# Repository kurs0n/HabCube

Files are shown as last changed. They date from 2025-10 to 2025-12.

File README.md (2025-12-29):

# HabCube

## Description

The "Intelligent Cube" is an IoT device that supports users in forming and maintaining daily habits. Habits are defined in a mobile application, which allows for configuration and the presentation of statistics regarding progress.

## Prototype Video
 
https://youtu.be/eo05IGiR9LY

## Introduction

The goal of this project is to create a complete Internet of Things (IoT) system designed to operate on a local network. The system combines hardware (the physical cube) with a mobile application that allows users to define, configure, and track their habits, as well as view statistics on their progress.

The project integrates knowledge from electronics, computer science, network programming, and embedded systems engineering. The work covers both the hardware layer (the cube's design and implementation) and the software layer (server-side communication, backend, mobile user interface, and overall system integration).

## Project Goals

### General Goals
- To create a fully functional IoT system operating within a local network.
- To achieve high effectiveness in helping users build and sustain positive habits.
- To design a system that increases user motivation and engagement in the process of self-improvement.
- To develop a final product that genuinely improves users' quality of life by supporting them in achieving their habit-related goals.

### Educational Goals
- To understand the practical aspects of building end-to-end IoT systems.
- To learn how to integrate hardware and software into a single cohesive system.
- To develop teamwork and project management skills.
- To gain experience in planning, implementing, testing, and documenting a complex technical project.
- To learn which motivational mechanisms are most effective in habit formation and how to design engaging and intuitive user interactions.

## Project Scope

### Key Features
- **Habit Configuration**: Defining and managing habits through a mobile application.
- **Progress Tracking**: Monitoring user progress and presenting it through statistics.
- **Motivational Feedback**: Providing users with visual, sound, and light-based "dopamine hits" to reinforce positive actions.

### System Architecture
The system consists of three main components:
1.  **The Intelligent Cube**: A physical device based on an ESP32 microcontroller that acts as the primary user interaction point.
2.  **Central Server**: A backend service responsible for handling communication with the cube, processing data, and storing user statistics.
3.  **Mobile Application**: A user interface for configuring the cube, defining habits, and viewing progress data.

All components communicate over a local Wi-Fi network.

---

## Tools and Technologies

### Software / Backend
* **Language:** Python 3.9+
* **Framework:** Flask
* **Database ORM:** SQLAlchemy
* **API Documentation:** Flasgger (Swagger UI)
* **Serialization:** Python Dataclasses (DTOs)
* **Deployment:** Google Cloud Run (Dockerized)

### Mobile App / UI
* **Framework:** React Native (Expo)
* **Language:** TypeScript
* **Navigation:** React Navigation
* **HTTP Client:** Axios
* **State Management:** React Hooks (Custom Hooks)
* **UI Components:** React Native Vector Icons (Ionicons), Safe Area Context

### 3D Design & Manufacturing
* **Software:** Autodesk Fusion 360
* **Files:** `HabCube.f3z` (Source), `.stl` (Production)
* **Method:** FDM 3D Printing (PLA/PETG)
* **Components:**
    * `new_cube.stl`: Main frame with screen mounts.
    * `new_cap.stl`: Protective lid/cover.

### Database
* **Engine:** PostgreSQL 13+
* **Production:** Google Cloud SQL
* **Caching:** Redis (Google Cloud Memorystore)

### Hardware
* **Microcontroller:** ESP32
* **Peripherals:** 4 OLED Screens (I2C, SPI), Gyroscope, Multiplexer, 2 Tact switches, Audio amplifier, Speaker, LEDs.

### DevOps & Management
* **Containerization:** Docker, Docker Compose
* **CI/CD:** GitHub Actions
* **Version Control:** Git, GitHub
* **Project Management:** GitHub Projects (Kanban board)

---

## Development Setup

### Environment Configuration

It is recommended to enable pre-commit hooks (instructions below).

**IMPORTANT:**
First, run the setup script which automatically adds `export CURRENT_UID` to your `~/.bashrc` (this avoids permission issues with files and folders later):

```bash
./setup-env.sh
source ~/.bashrc
```

### First Run
```bash
# 1. Build the image
docker-compose up -d --build

# 2. Check container status (or use GUI)
docker-compose ps

# 3. View logs
docker-compose logs -f backend

# 4. Check app health
curl http://localhost:5000/health
```
### Running the Application
```bash
# You can run it via Docker Compose or using the MAKEFILE
docker-compose up -d

# Stop
docker-compose down
```
### Using Makefile (Recommended)
The Makefile automatically exports CURRENT_UID:
```bash
make init      # First run / Initialization
make up        # Start services
make down      # Stop services
make logs      # View logs
make test      # Run tests
make help      # View all commands
```
### Services Access
Backend: http://localhost:5000

Adminer (DB UI): http://localhost:8080

PostgreSQL: localhost:5432

Redis: localhost:6379
### Common Commands
```bash
# Basic Docker
docker-compose up -d
docker-compose down
docker-compose logs -f
docker-compose ps

# Rebuild
docker-compose build
docker-compose up -d --build

# Shell Access
docker-compose exec backend bash

# Tests and Code Quality
docker-compose exec backend pytest
docker-compose exec backend pytest --cov=app
docker-compose exec backend flake8 app/
docker-compose exec backend black app/
docker-compose exec backend pylint app/
docker-compose exec backend mypy app/

# Database Management
docker-compose exec postgres psql -U habcube_user -d habcube
docker-compose exec backend flask db migrate -m "description"
docker-compose exec backend flask db upgrade

# Makefile
make help
```
### Pre-commit Hook
The pre-commit hook runs code quality checks automatically.
```bash
# 1. Create a symlink to the hook
ln -sf ../../pre-commit .git/hooks/pre-commit

# 2. Grant permissions
chmod +x pre-commit
```
### Checks performed:

Black (formatting), isort (import sorting)

Flake8 (style), Pylint (quality), MyPy (types)

You can also run these manually:
```bash
make lint      # Check code
make format    # Auto-format
make test      # Run tests
make quality   # Run all checks
```

## Database Schema

### Table: habits
| Column | Type | Description |
| :--- | :--- | :--- |
| `id` | INTEGER PRIMARY KEY | Unique habit identifier. |
| `name` | VARCHAR(100) | Name of the habit (e.g., "Drink water"). |
| `description` | TEXT | Optional description or motivation. |
| `deadline_time` | TIME | Deadline for completing the habit (e.g., 21:00). |
| `frequency` | ENUM | Frequency: `daily`, `weekly`, `monthly`, `hourly`, etc. |
| `active` | BOOLEAN | Whether the habit is active (Default: `TRUE`). |
| `created_at` | TIMESTAMP | Creation timestamp (Default: `CURRENT_TIMESTAMP`). |
| `color` | VARCHAR(10) | Color associated with the habit (for UI/LEDs). |
| `icon` | ENUM | Icon identifier for the UI. |

### Table: habit_tasks
| Column | Type | Description |
| :--- | :--- | :--- |
| `id` | INTEGER PRIMARY KEY | Unique task identifier. |
| `habit_id` | INTEGER FK | Foreign key referencing `habits(id)`. |
| `date` | DATE | The date the habit was intended for/completed. |
| `completed` | BOOLEAN | Completion status (Default: `FALSE`). |
| `completion_time` | TIMESTAMP | Exact timestamp of completion (UTC). |

### Table: habit_statistics
| Column | Type | Description |
| :--- | :--- | :--- |
| `id` | INTEGER PRIMARY KEY | Unique statistics record identifier. |
| `habit_id` | INTEGER FK | Foreign key referencing `habits(id)`. |
| `total_completions` | INTEGER | Total count of successful completions. |
| `current_streak` | INTEGER | Current count of consecutive completions. |
| `best_streak` | INTEGER | Highest streak ever achieved for this habit. |
| `success_rate` | FLOAT | Percentage of successful completions vs opportunities. |
| `last_completed` | DATE | Date of the last successful completion. |
| `updated_at` | TIMESTAMP | Last time statistics were recalculated. |

### ER Diagram:


## Data Flow
### Configuration and Creation of a New Habit
```mermaid
graph TD
    A[START: User wants to create a new habit] --> B(Mobile App: POST /api/v1/habits with JSON);

    subgraph Data Validation and DTO
        B --> C1{Backend: Validate deadline_time format HH:MM};
        C1 -- Format Error / Invalid Frequency --> Z400[Return 400: Invalid Input];
        C1 -- OK --> C2{Backend: Validate frequency FrequencyType};
        C2 -- OK --> D(Backend: Create and validate CreateHabitDTO);
    end

    D -- Validation Error --> Z400;
    D -- Validation OK --> E(Backend: Create Habit object);

    subgraph Database Transaction
        E --> F1(DB: Add Habit flush by ID);
        F1 --> F2(DB: Create HabitStatistics with habit_id);
        F2 --> G(DB: Commit - Save both records);
        G -- Commit/DB Error --> Z500[DB: Rollback and Return 500];
    end

    G --> H(Backend: Return 201 Created);
    
    subgraph Post-Creation Actions
        H --> H1(Notification Service: Schedule Reminders based on Frequency);
        H --> I(Mobile App: Success Confirmation);
        I --> J{Async: Backend sends config to Cube};
        J --> K(Intelligent Cube: Update Screens/Local Config);
    end

    K --> L[END: New habit ready];

    Z400 --> ZK[END: Process finished with error];
    Z500 --> ZK;
```

### Execution and Confirmation of Habit (Cube Interaction)
```mermaid
graph TD
    A[START: User rotates and presses Tact Switch] --> B(Intelligent Cube: Detect face and send POST /api/v1/habits/id/complete);
    B --> C(Backend: Get Habit - habit_id);
    C -- No Habit --> Z404[Return 404: Habit not found];

    subgraph Verification and Task
        C -- Habit OK --> D{Backend: Check if completed today?};
        D -- Yes --> Z400[Return 400: Already completed today];
        D -- No --> E(Backend: Create HabitTask and add to session);
    end

    subgraph Statistics and Gamification Update
        E --> F(Backend: Get/Create HabitStatistics);
        F --> G(Backend: Update total_completions, last_completed);
        
        %% NEW FUNCTIONALITY: Gamification
        G --> G1(Backend: Calculate XP gained & Check Level Up);
        
        G1 --> H{Backend: Check previous Task completion};
        H -- 1 day difference --> I(current_streak += 1);
        H -- Other case --> J(current_streak = 1);
        I --> K(Backend: Update Best Streak);
        J --> K;
    end

    K --> L(DB: Commit - Save Task, Stats, and XP);
    L -- Commit/DB Error --> Z500[DB: Rollback and Return 500];

    L --> M(Backend: Return 200 OK + XP gained);
    M --> N(Intelligent Cube: Trigger Motivational Feedback LEDs, Sound);
    N --> O[END: Execution Confirmed];

    Z404 --> ZK[END: Error];
    Z400 --> ZK;
    Z500 --> ZK;
```
### Monitoring Progress and Statistics
```mermaid
graph TD
    A[START: User opens Mobile App] --> B{User: View List or Details?};

    subgraph Habit List
        B -- List (GET /habits) --> B1(Mobile App: GET /api/v1/habits);
        B1 --> B2(Backend: Habit.query.all);
        B2 -- DB Error --> Z500_G[Return 500];
        B2 -- OK --> B3(Backend: Convert to Habit DTO list);
        B3 --> B4(Mobile App: Display List);
    end

    subgraph Habit Details with Filters
        B -- Details (GET /habits/id) --> C0{Check: Date Filters applied?};
        
        C0 -- Yes --> C1_F(Mobile App: GET /api/v1/habits/id?start_date=X&end_date=Y);
        C0 -- No --> C1(Mobile App: GET /api/v1/habits/id);
        
        C1_F --> C2(Backend: Get Habit from DB);
        C1 --> C2;

        C2 -- Habit not found --> Z404_G[Return 404];
        C2 -- OK --> C3(Backend: Attach HabitStatistics);
        
        C3 --> C3_A{Filter Tasks by Date?};
        C3_A -- Yes --> C3_B(Backend: Filter HabitTasks query by range);
        C3_A -- No --> C3_C(Backend: Fetch recent HabitTasks);
        
        C3_B --> C4(Backend: Return Habit DTO with Statistics & Filtered History);
        C3_C --> C4;
        
        C4 --> C5(Mobile App: Display Statistics and History);
    end

    C5 --> K[END: Data Displayed];
    B4 --> K;
    Z500_G --> K_E[END: Error];
    Z404_G --> K_E;
```

### Detailed Functionalities
| ID | Category | Functionality | Description |
| :--- | :--- | :--- | :--- |
| **A1** | **Habit Management** | **Create/Configure** | Enables adding a new habit (name, description), setting **frequency** (`daily`, `weekly`, etc.) and optional **deadline**. |
| **A2** | **Habit Management** | **Activate Daily Set** | User **manually activates** a list of habits to perform on a given day, which is then sent to the cube. |
| **A3** | **Habit Management** | **Edit/Delete** | Enables modification of existing habit parameters or removing it completely from the system. |
| **A4** | **Monitoring** | **Progress Visualization** | Presentation of statistics: **Total Completions**, **Current Streak**, **Best Streak**. |
| **A5** | **Monitoring** | **Completion History** | Displays a detailed calendar or task list (`HabitTask`) with completion dates/times. |
| **A6** | **Cube Interaction** | **Pairing/Config** | Enables connecting to the cube on the local network and **assigning habits to the cube's screens**. |

### Intelligent Cube (Hardware)
| ID | Category | Functionality | Description |
| :--- | :--- | :--- | :--- |
| **C1** | **State Display** | **Display Habits** | **OLED Screens** display the **active habit** for the day along with its current status. |
| **C2** | **Interaction** | **Change Active Habit** | **Pressing the Tact Switch** on the active face changes the displayed habit (e.g., "Reading" -> "Running"). |
| **C3** | **Interaction** | **Confirm Completion** | **Rotating the cube** onto a specific face (detected by **Gyroscope**) confirms task completion. |
| **C4** | **Motivation** | **Sensory Feedback** | Upon completion (C3), the cube provides **Motivational Feedback**: **LEDs** flash and **Speaker** plays a sound. |
| **C5** | **Communication** | **Send Data** | After confirmation, sends `POST /api/v1/habits/{id}/complete` to the Central Server. |
| **C6** | **Communication** | **Receive Configuration** | Cube receives active habits list from Central Server and updates displays dynamically. |

### Deployment on Google Cloud (FOR ADMIN A.D. ONLY)
The application is ready for deployment on Google Cloud Platform with the following services:
- Cloud Run - Serverless Flask backend
- Cloud SQL for PostgreSQL - Managed database
- Memorystore for Redis - Managed cache
- Secret Manager - Secure credential storage

### Using the API (GCLOUD)
- Authenticate:
```bash
gcloud auth login
```
- Generate Token:
```bash
TOKEN=$(gcloud auth print-identity-token)
```
- Test via Curl:
```bash
curl [https://backend-1089871134307.europe-west1.run.app/api/v1/habits](https://backend-1089871134307.europe-west1.run.app/api/v1/habits)
```

## API Reference (Endpoints)
### Habit Management Endpoints
| Method | Endpoint | Description | Required Data |
| :--- | :--- | :--- | :--- |
| **GET** | `/habits` | Retrieves a list of all defined habits. | - |
| **POST** | `/habits` | Creates a new habit. | JSON: `name`, `frequency`, `type`, etc. |
| **GET** | `/habits/{id}` | Retrieves details of a specific habit with stats. | `id` (int) in URL |
| **POST** | `/habits/{id}/complete` | Marks a habit as completed for today. | `id` (int) in URL |
| **GET** | `/habits/active` | Retrieves habits "ready" to be completed now. | - |
| **GET** | `/finished-habits` | Retrieves archived habits with success status. | - |

### System Endpoints
| Method | Endpoint | Description |
| :--- | :--- | :--- |
| **GET** | `/statistics` | Returns global user statistics (total habits, streaks). |
| **GET** | `/health` | Health check - verifies service and DB status. |****

# HabCube Mobile Application Documentation

## 1. Overview
The HabCube mobile application is a cross-platform solution built with **React Native** and **TypeScript**. It acts as the primary user interface for configuring habits, tracking progress, and visualizing statistics from the IoT Cube.

## 2. Technology Stack

* **Framework:** React Native (0.81.4)
* **Language:** TypeScript (5.9.2)
* **Build Tool:** Expo / React Native CLI
* **Navigation:** React Navigation (Native Stack)
* **State Management:** React Hooks (`useState`, `useEffect`, Custom Hooks)
* **HTTP Client:** Axios
* **UI Libraries:**
    * `react-native-vector-icons` (Ionicons)
    * `react-native-safe-area-context`
    * `@react-native-picker/picker`
    * `@react-native-community/datetimepicker`
    * `react-native-toast-message`

## 3. Project Structure

The project follows a **Feature-based / Component-folder** structure:

```text
src/
├── api/                  # API communication layer
│   ├── client.ts         # Axios instance configuration
│   ├── endpoints.ts      # API URL constants
│   └── habits.api.ts     # Service functions (GET, POST)
├── assets/
│   ├── data/
│   │   └── icons.ts      # List of available habit icons
│   └── iconNoBg1.png     # Application logo
├── components/           # UI Components & Screens
│   ├── AddHabit/         # Habit creation screen
│   ├── AppLogo/          # Reusable logo component
│   ├── BottomNavbar/     # Custom bottom navigation bar
│   ├── FinishedHabits/   # History screen
│   ├── HabitsStats/      # Statistics screen
│   ├── MainPage/         # Dashboard (Active habits)
│   └── WelcomeScreen.tsx # Intro screen
├── constants/
│   └── config.ts         # Environment configuration (API URL)
├── hooks/                # Business Logic (Custom Hooks)
│   ├── useCreateHabit.ts
│   ├── useFinishedHabits.ts
│   ├── useHabits.ts
│   └── useStatsHabits.ts
└── types/
    └── habit.types.ts    # TypeScript interfaces
```
## 4. Architecture & Data Flow
### The application uses the Service-Hook-Component pattern to separate concerns:
- API Layer (src/api): Handles direct HTTP communication using Axios. It defines endpoints and raw data fetching functions.

- Hooks Layer (src/hooks): Encapsulates business logic and state management. It calls the API layer and exposes simple variables (data, loading, error) to the UI.

- UI Layer (src/components): Purely presentational components that consume Hooks to display data.

### Example Flow: Fetching Habits
- Component (MainPage) mounts and calls useHabits().

- Hook (useHabits) sets loading=true and calls getHabits() from API.

- API (habits.api.ts) performs GET /habits via Axios.

- Backend returns JSON data.

- Hook updates habits state and sets loading=false.

- Component re-renders with the habit list.

### Configuration (config.ts)
The application automatically detects the running environment to set the correct Backend URL:

- Android Emulator: Uses 10.0.2.2:5000 (Access to host localhost).

- iOS Simulator: Uses localhost:5000.

- Physical Device: Requires manual IP configuration or network tunneling (if not deployed to cloud).

### Key Components Description
| Component | Description |
| :--- | :--- |
| **WelcomeScreen** | Initial landing page with a "Start" button. |
| **MainPage** | The dashboard displaying active habits, current streaks, and a 21-day progress bar. Allows checking completion status. |
| **AddHabit** | A form to create new habits with validation. Users choose name, icon, frequency, and type. |
| **FinishedHabits** | A list of archived or completed habits showing final stats and success status. |
| **HabitsStats** | Global statistics dashboard (Total habits, Longest streak, Completion rate). |
| **BottomNavbar** | Custom navigation bar visible on main screens, handling routing. |
---

# Frontend Setup Guide

## Prerequisites

Before running the mobile application, ensure you have:

1.  **Node.js** (LTS version recommended) installed.
2.  **npm** or **yarn** package manager.
3.  **Mobile Development Environment:**
    * **Android:** Android Studio with configured Android SDK and Emulator.
    * **iOS (macOS only):** Xcode with iOS Simulator.
4.  **Backend Running:** The Flask backend must be running on port `5000`.

## Installation

1.  Navigate to the project root directory:
    ```bash
    cd habcube
    ```

2.  Install dependencies:
    ```bash
    npm install
    # or
    yarn install
    ```

3.  Link assets (if using React Native CLI specific fonts/icons):
    ```bash
    npx react-native-asset
    ```

## Running the Application

### 1. Start Metro Bundler
Start the JavaScript bundler in a dedicated terminal:
```bash
npm start
```
### 2. Run on Emulator/Simulator
For Android: Ensure your Android Emulator is running (visible in Android Studio Device Manager).
```bash
npm run android
```
### For iOS (macOS only):
```bash
npm run ios
```

Rebuild the app (npm run android / npm run ios).

# 3D Design & Enclosure Documentation

## 1. Overview
The physical enclosure of the HabCube is designed to be compact, ergonomic, and durable. It houses the central ESP32 microcontroller, four OLED screens, sensors, and the power supply unit. The design focuses on modularity and ease of assembly using standard FDM 3D printing technology.

## 2. Design Tools & Source Files
* **CAD Software:** Autodesk Fusion 360
* **Source File:** `HabCube.f3z` (Contains full assembly, parametric history, and component constraints).
* **Export Format:** `.stl` (Stereolithography) for slicing and printing.

## 3. Component Breakdown

The enclosure consists of two primary parts designed to fit together seamlessly:

### 3.1 Main Body (`new_cube.stl`)
The core structural component of the device.
* **Function:** Houses the main electronics (ESP32, Multiplexer, Gyroscope, Battery) and holds the display panels.
* **Key Features:**
    * **OLED Cutouts:** Four precise rectangular openings sized for 0.96" OLED displays (I2C/SPI) located on the side faces.
    * **Mounting Points:** Internal standoffs/slots for securing the PCB and ESP32 module.
    * **Cable Management:** Internal channels to route wires from the central controller to the peripheries without pinching.
    * **Sensor Bay:** Dedicated space for the MPU6050 gyroscope to ensure accurate rotation tracking.

### 3.2 Top Cap (`new_cap.stl`)
The closing mechanism for the enclosure.
* **Function:** Seals the device, protecting internal components from dust and damage.
* **Key Features:**
    * **Access:** Designed to be removable for maintenance or battery replacement.
    * **Speaker Grille:** (Optional based on design) Perforations to allow sound from the internal buzzer/speaker to escape clearly.
    * **Switch Access:** Integrated flexible area or cutout for the Tact Switches (Reset/Boot or Custom interactions).

## 4. Design Specifications

| Feature | Specification |
| :--- | :--- |
| **Dimensions** | Approx. 60mm x 60mm x 60mm (Standard handheld cube size) |
| **Wall Thickness** | 2.0mm - 3.0mm (Optimized for rigidity vs. print time) |
| **Tolerance** | 0.2mm clearance for snap-fit/sliding parts |
| **Material** | PLA (Polylactic Acid) or PETG |

## 5. 3D Printing Guidelines

Recommended settings for reproducing the HabCube parts on a standard FDM printer (e.g., Prusa i3, Ender 3).

### General Settings
* **Nozzle Diameter:** 0.4mm
* **Layer Height:** 0.2mm (Quality) or 0.24mm (Draft)
* **Infill:** 15% - 20% (Grid or Gyroid pattern for strength)
* **Shells/Perimeters:** 3 (To ensure wall strength for mounting screws)

### Specific Instructions
* **Supports:**
    * *Main Body:* Required for the OLED window bridges. Use "Tree Supports" for easier removal.
    * *Cap:* Generally prints flat without supports.
* **Orientation:** Print the main body with the largest flat face down (usually the bottom) to maximize bed adhesion.

## 6. Assembly Instructions
1.  **Preparation:** Remove all support material and sand the edges if necessary.
2.  **Screen Mounting:** Insert the 4 OLED screens into their respective slots. Secure with hot glue or small M2 screws depending on the mounting holes.
3.  **Electronics:** Place the wiring harness and ESP32 into the center. Ensure the gyroscope is aligned with the cube's axes.
4.  **Closing:** Snap or screw the `new_cap.stl` onto the `new_cube.stl`.

## Changelog
2025-10-20
### Google Cloud Deployment Ready

- Backend Configuration

    - Updated config.py to support Cloud SQL (127.0.0.1) and Memorystore.

    - Added support for environment variables: DB_HOST, DB_USER, REDIS_HOST, etc.

    - Maintained compatibility with local Docker Compose.

- Dockerfile Improvements

    - Added support for the PORT variable (required by Cloud Run).

    - Updated CMD to use ${PORT:-5000}.

    - Health check now uses the dynamic port.

- Deployment Tools

    - Created deploy-gcloud.sh - interactive deployment script.

    - Created .env.gcloud.template - GCP configuration template.

### 2025-10-15
### Habits API - Initial Implementation

- Models

    - Created Habit model - stores user habits.

    - Created HabitTask model - registers habit executions.

    - Created HabitStatistics model - statistics and streaks.

    - Added database migrations.

- Enums and DTOs

    - FrequencyType enum: every_30_min, hourly, every_3_hours, every_6_hours, daily, weekly, monthly.

    - CreateHabitDTO - input data validation.

    - HabitResponseDTO - API response format.

- Endpoints

    - GET /api/v1/habits - list of all habits.

    - GET /api/v1/habits/{id} - habit details with statistics.

    - POST /api/v1/habits - create new habit.

    - POST /api/v1/habits/{id}/complete - mark habit as completed.

- Documentation

    - Swagger/Flasgger integration.
    
    - Request/Response examples for each endpoint.
    
    - Available at: http://localhost:5000/api/docs/

- Tests
    - Tests for all endpoints.

    - Data validation tests.

    - Error case tests (404, 400).

    - Statistics and streak tracking tests.

## Team
- Piotr Ziobrowski - Embedded programming, Cube 3D project

- Szymon Domagała - Frontend, UI

- Paweł Klocek - Database, Backend, Documentation

- Aleksy Dąda - Backend, Docker

- Patryk Kurek - Hardware, Embedded programming, Tech Lead

Special thanks to: https://github.com/amora-labs/micropython-captive-portal/blob/master/captive.py

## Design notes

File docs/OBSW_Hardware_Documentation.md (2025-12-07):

# HabCube - Complete Hardware & OBSW Documentation

> **Project:** Intelligent Habit Tracking Cube
> **Version:** 2.0
> **Last Updated:** December 7, 2025
> **Authors:** Patryk Kurek, Piotr Ziobrowski

---

## Table of Contents

1. [Hardware Components](#hardware-components)
2. [Electronic Schematic](#electronic-schematic)
3. [OBSW Architecture](#obsw-architecture)
4. [Core Systems](#core-systems)
5. [API Integration](#api-integration)
6. [System Workflows](#system-workflows)
7. [Technical Achievements](#technical-achievements)
8. [Troubleshooting](#troubleshooting)
9. [Future Enhancements](#future-enhancements)

---

## Hardware Components

### Microcontroller

**Board:** [Raspberry Pi Pico WH](https://botland.com.pl/moduly-i-zestawy-do-raspberry-pi-pico/21575-raspberry-pi-pico-wh-rp2040-arm-cortex-m0-cyw43439-wifi-ze-zlaczami-5056561800196.html)

**Specifications:**
- **Processor:** Dual-core ARM Cortex-M0+ (RP2040)
- **Clock Speed:** Up to 133 MHz
- **Memory:** 264 KB SRAM, 2 MB Flash
- **WiFi:** CYW43439 2.4GHz 802.11n wireless chip
- **GPIO:** 26 multi-function pins with pre-soldered headers
- **Interfaces:** 2x UART, 2x SPI, 2x I2C, 16x PWM channels

**Datasheets:**
- [RP2040 Technical Reference](https://datasheets.raspberrypi.com/rp2040/rp2040-datasheet.pdf)
- [Pico W Datasheet](https://datasheets.raspberrypi.com/picow/pico-w-datasheet.pdf)

---

### Sensors & Peripherals

#### Motion Sensor
**Model:** SparkFun MPU-9250 9DoF (9 Degrees of Freedom)

**Specifications:**
- **Gyroscope:** 3-axis, ±250 to ±2000 °/s
- **Accelerometer:** 3-axis, ±2g to ±16g
- **Magnetometer:** 3-axis AK8963 compass
- **Interface:** I2C (address 0x68)
- **Resolution:** 16-bit ADC
- **Update Rate:** Up to 8 kHz (gyro/accel)

**Purpose:** Detects cube rotation for habit completion trigger

**Datasheet:** [MPU-9250 Specifications](https://botland.com.pl/index.php?controller=attachment&id_attachment=2716)

---

#### Display System
**Model:** OLED Screen 1.3" (128x64 pixels) - SH1106 Driver

**Specifications:**
- **Resolution:** 128x64 pixels (monochrome)
- **Driver IC:** SH1106
- **Interface:** SPI (4-wire)
- **Voltage:** 3.3V - 5V
- **Viewing Angle:** >160°
- **Contrast:** Software adjustable

**Configuration:** Single display (optimized from previous dual-display setup)

**Purpose:** Display habit icons, names, status messages, and animations

**Resources:**
- [SH1106 Datasheet](https://sklep.msalamon.pl/download/127859/?tmstv=1756190702)
- [Setup Guide](https://sklep.msalamon.pl/blog/instrukcja-uruchomienia-wyswietlacza-oled-128x64-sh1106/)
- [Bitmap Generator Guide](https://sklep.msalamon.pl/blog/instrukcja-tworzenia-bitmap-z-obrazow-na-bazie-generatora-online/)

---

#### User Input
**Model:** [2x Membrane Switch (Self-Adhesive)](https://botland.com.pl/klawiatury-arduino/17118-klawiatura-membranowa-1-szary-klawisz-samoprzylepna-5904422326920.html)

**Specifications:**
- **Type:** Single-key membrane keypad
- **Mounting:** Self-adhesive backing
- **Color:** Grey
- **Actuation:** Tactile feedback
- **Interface:** Simple switch closure (active low)

**Button Functions:**
- **Button 1 (GPIO 17):** Navigate to previous habit
- **Button 2 (GPIO 16):** Navigate to next habit
- **Both pressed:** Reload active habits from server

**Product Link:** [Membrane Switch](https://botland.com.pl/klawiatury-arduino/17118-klawiatura-membranowa-1-szary-klawisz-samoprzylepna-5904422326920.html)

---

#### Audio Feedback
**Model:** Grove Passive Buzzer (Seeedstudio 107020109)

**Specifications:**
- **Type:** Passive piezoelectric buzzer
- **Frequency Range:** 2kHz - 5kHz
- **Operating Voltage:** 3.3V - 5V
- **Sound Pressure:** ≥85dB @ 10cm
- **Resonant Frequency:** 2.7kHz ± 300Hz

**Purpose:** Play Mario theme song on habit completion (PWM-driven melodies)

**Datasheet:** [MLT-8530 Buzzer](https://files.seeedstudio.com/products/107020109/document/MLT_8530_datasheet.pdf)

---

### GPIO Pin Assignments

#### SPI Display (OLED)
| Function | GPIO Pin | Description |
|---|---|---|
| SCK | 2 | SPI Clock |
| MOSI | 3 | Master Out Slave In |
| CS | 4 | Chip Select (active low) |
| DC | 5 | Data/Command select |
| RST | 6 | Hardware Reset |
| **Bus** | SPI0 | Hardware SPI controller |

#### I2C Gyroscope (MPU-9250)
| Function | GPIO Pin | Description |
|---|---|---|
| SDA | 0 | I2C Data Line |
| SCL | 1 | I2C Clock Line |
| **Bus** | I2C0 | Hardware I2C controller |
| **Address** | 0x68 | Default I2C address |

#### User Interface
| Component | GPIO Pin | Configuration |
|---|---|---|
| Button 1 | 17 | INPUT with PULL_UP |
| Button 2 | 16 | INPUT with PULL_UP |
| Buzzer (PWM) | 22 | PWM Output |

**Note:** Buttons are active-low (pressed = 0, released = 1)

---

### Power Supply Specifications

**Input:** 5V USB-C (Raspberry Pi Pico WH standard)

**Current Consumption:**
- **Pico W (WiFi Active):** 80-100 mA
- **OLED Display:** 20 mA
- **MPU-9250:** 3.5 mA (all sensors)
- **Buzzer (Active):** 30 mA peak
- **Total (Typical):** ~110-125 mA @ 5V = **0.55-0.62W**
- **Total (Peak):** ~155 mA @ 5V = **0.78W** (during audio playback)

---

## Electronic Schematic

### Schematic Files Location
- **PDF:** `docs/schema/Schematic_IOT2025_2025-10-29.pdf`
- **PNG:** `docs/schema/Schematic_IOT2025_2025-10-29.png`
- **SVG:** `docs/schema/Schematic_IOT2025_2025-10-29.svg`

### Connection Summary

```
Raspberry Pi Pico WH (RP2040)
    │
    ├─── I2C0 (GPIO 0,1) ────► MPU-9250 Gyroscope
    │
    ├─── SPI0 (GPIO 2,3,4,5,6) ────► SH1106 OLED Display
    │
    ├─── GPIO 16 ────► Button 2 (Next Habit)
    │
    ├─── GPIO 17 ────► Button 1 (Previous Habit)
    │
    ├─── GPIO 22 (PWM) ────► Passive Buzzer
    │
    └─── WiFi (CYW43439) ────► Cloud Backend (Google Cloud Run)
```

---

## OBSW Architecture

### Technology Stack
- **Language:** MicroPython (optimized for RP2040)
- **Firmware:** Raspberry Pi Pico W MicroPython v1.20+
- **Protocol:** HTTP/REST (requests library)
- **Data Format:** JSON
- **Threading:** `_thread` module for async audio playback

---

### Project Structure

```
obsw/
├── main.py                         # Application entry point & main loop
├── captive/
│   └── captive.py                 # WiFi captive portal system
├── display/
│   └── display.py                 # OLED display management
├── drivers/
│   ├── gyroscope/
│   │   ├── mpu9250.py            # Main 9DoF sensor driver
│   │   ├── mpu6500.py            # Gyro/Accel component
│   │   └── ak8963.py             # Magnetometer component
│   └── oled/
│       ├── sh1106.py             # SH1106 OLED driver (SPI/I2C)
│       └── sh1106.pyi            # Type hints
├── music.py                       # Audio playback (Mario theme)
├── icons.py                       # Habit icon generator (vector graphics)
├── gif/                           # Animation frames (55 BMP files)
│   ├── resized_0.bmp
│   ├── resized_1.bmp
│   └── ... (resized_54.bmp)
├── clear.py                       # Utility script
└── wlan.info                      # WiFi credentials (auto-generated)
```

---

## Core Systems

### 1. Captive Portal WiFi Configuration

**File:** `captive/captive.py`

#### Purpose
Provides seamless WiFi setup when device cannot connect to saved credentials. Creates an access point with web interface for network configuration.

#### Features
✅ Automatic AP mode on connection failure
✅ Network scanning with SSID deduplication
✅ Responsive HTML5 web interface
✅ Credential validation and storage
✅ Auto-reboot after successful connection

#### Implementation Details

**Access Point Configuration:**
```python
ap.config(essid="HabCube", password="habcube2115")
```

**Network Scanning:**
```python
def fetch_networks(wlan):
    scan_results = wlan.scan()
    found_ssids = set()  # Deduplication
    for result in scan_results:
        ssid = result[0].decode('utf-8')
        if ssid and ssid not in found_ssids:
            found_ssids.add(ssid)
            ssid_options += f'<option value="{ssid}">{ssid}</option>'
    return ssid_options
```

**Web Server:**
- **Port:** 80 (HTTP)
- **Socket Timeout:** 2 seconds
- **Method:** POST for credential submission
- **Persistent Storage:** `wlan.info` file (space-separated SSID and password)

**HTML Interface Highlights:**
- Modern CSS3 with flexbox layout
- Mobile-responsive (viewport meta tag)
- Dropdown network selector (auto-populated)
- Password input with type="password"
- Visual feedback during connection attempt

**Connection Flow:**
```
1. User connects to "HabCube" WiFi
2. Opens browser → Captive portal detected
3. Selects network from dropdown
4. Enters password
5. Clicks "Connect"
6. Device validates credentials (10s timeout)
7. On success: Saves to wlan.info → Reboots
8. On failure: Shows "Wrong Credentials!" message
```

---

### 2. Display Management System

**File:** `display/display.py`

#### Architecture Update
**Optimization:** Refactored from dual-display to **single display instance** for improved performance and reduced memory usage.

**Display Initialization:**
```python
spi_oled1 = SPI(0, baudrate=1000000, sck=Pin(2), mosi=Pin(3))
cs_oled1 = Pin(4, Pin.OUT, value=1)
dc_oled1 = Pin(5, Pin.OUT)
rst_oled1 = Pin(6, Pin.OUT)

displays = SH1106_SPI(128, 64, spi_oled1, dc_oled1, rst_oled1, cs_oled1,
                      rotate=0, delay=0)
```

#### Key Functions

##### 1. Centered Text Display
```python
def display_text_centered(text):
    """
    Displays multi-line centered text.
    Automatically wraps text at 16 characters per line.
    """
    displays.fill(0)  # Clear screen

    MAX_CHARS_PER_LINE = 16
    lines = [text[i:i+MAX_CHARS_PER_LINE]
             for i in range(0, len(text), MAX_CHARS_PER_LINE)]

    total_text_height = len(lines) * 8  # 8px per line
    y_start = (64 - total_text_height) // 2  # Vertical center

    for i, line in enumerate(lines):
        x_pos = (128 - len(line) * 8) // 2  # Horizontal center
        y_pos = y_start + (i * 8)
        displays.text(line, x_pos, y_pos, 1)

    displays.show()
```

**Use Cases:**
- WiFi connection status
- Error messages
- Loading screens

##### 2. Active Habit Display
**New Feature:** Empty habit list handling + text truncation

```python
def display_active_habit(active_habits, active_habit_index):
    # Safety check for empty list
    if len(active_habits) <= 0:
        display_text_centered("No active habits try adding one in mobile app")
        return

    habit_name = active_habits[active_habit_index]["name"]
    displays.fill(0)

    # Icon positioning (80x48px icons)
    x_icon = (128 - 80) // 2  # Center horizontally

    # Icon selection based on habit type
    habit_type = active_habits[active_habit_index]["type"]
    if habit_type == "water":
        displays.blit(icons.fb_glass, x_icon, 0)
    elif habit_type == "sport":
        displays.blit(icons.fb_sport, x_icon, 0)
    elif habit_type == "language":
        displays.blit(icons.fb_lang, x_icon, 0)
    elif habit_type == "read":
        displays.blit(icons.fb_glasses, x_icon, 0)
    elif habit_type == "code":
        displays.blit(icons.fb_code, x_icon, 0)

    # Text truncation (NEW: prevents overflow)
    max_chars = 16
    if len(habit_name) > max_chars:
        habit_name = habit_name[:max_chars - 3] + "..."

    # Centered text below icon
    text_length = len(habit_name) * 8
    x_text = max(0, (128 - text_length) // 2)
    displays.text(habit_name, x_text, 52, 1)
    displays.show()
```

**Supported Habit Types:**
| Type | Icon | Description |
|---|---|---|
| `water` | Glass | Water drinking reminder |
| `sport` | Dumbbell | Exercise tracking |
| `language` | Book/Flag | Language learning |
| `read` | Glasses | Reading habit |
| `code` | Terminal | Coding practice |

##### 3. Animation Playback
```python
def play_animation(frame_delay_ms=5):
    """
    Plays BMP animation sequence (55 frames @ 200 FPS).
    Reads bitmap files from flash storage.
    """
    frame_number = 1
    while True:
        filename = f"resized_{frame_number}.bmp"
        try:
            with open(filename, "rb") as f:
                f.seek(10)  # Skip BMP header to pixel data offset
                data_offset = int.from_bytes(f.read(4), "little")
                f.seek(data_offset)
                buffer = f.read()

                # Create framebuffer from bitmap data
                fb = framebuf.FrameBuffer(bytearray(buffer), 128, 64,
                                         framebuf.MONO_HLSB)

                displays.fill(0)
                displays.blit(fb, 0, 0)
                displays.show()

                utime.sleep_ms(frame_delay_ms)
                frame_number += 1
        except OSError:
            break  # End of animation sequence
```

**Animation Details:**
- **Frame Count:** 55 frames
- **Resolution:** 128x64 monochrome
- **Format:** Windows BMP (1-bit)
- **Frame Rate:** 200 FPS (5ms delay)
- **Total Duration:** ~275ms per loop
- **Trigger:** Habit completion celebration

---

### 3. Gyroscope-Based Rotation Detection

**File:** `main.py` (lines 91-99, 128-183)

#### Calibration Algorithm
**Purpose:** Eliminate sensor bias and drift for accurate rotation tracking

```python
def calibrate_gyro(samples=200):
    """
    Averages 200 gyroscope readings to calculate Z-axis offset.
    Must be performed with device stationary.
    """
    print("Calibrate gyroscope...")
    sum_z = 0
    for _ in range(samples):
        sum_z += sensor.gyro[2]  # Z-axis (vertical rotation)
        utime.sleep_ms(5)

    offset_z = sum_z / samples
    print(f"Calibrated gyroscope. Offset Z: {offset_z}")
    return offset_z
```

**Calibration Stats:**
- **Sample Count:** 200
- **Sample Rate:** 200 Hz (5ms interval)
- **Total Time:** 1 second
- **Purpose:** Removes static bias from manufacturing tolerances

#### Rotation Integration
**Method:** Discrete integration of angular velocity

```python
# Main loop (runs at ~100 Hz)
current_time = utime.ticks_ms()
dt = utime.ticks_diff(current_time, last_time) / 1000.0  # Time delta in seconds
last_time = current_time

gyro_z_raw = sensor.gyro[2]  # Read Z-axis gyro (rad/s)

# Apply calibration offset
gyro_z_rad = gyro_z_raw - gyro_offset_raw

# Convert to degrees/second
gyro_z_deg = gyro_z_rad * 57.296  # 180/π

# Dead-zone filtering (eliminate drift from micro-vibrations)
if abs(gyro_z_deg) < 0.5:
    gyro_z_deg = 0

# Integration: angle = angle + angular_velocity * time
angle_z += gyro_z_deg * dt
```

**Parameters:**
- **Dead Zone:** 0.5 °/s (prevents false positives)
- **Threshold:** 160° rotation
- **Direction:** Bidirectional (|angle| >= 160)

#### Completion Trigger
```python
if abs(angle_z) >= 160:
    print("Rotation detected!")

    # Non-blocking audio (separate thread)
    _thread.start_new_thread(music.play_mario_main_theme, (buzzer,))

    # Visual feedback (5 loops of 55-frame animation)
    play_sui_animation()

    # Backend API call
    complete_and_switch_habit()

    # Update display
    display.display_active_habit(active_habits, active_habit_index)

    # Reset rotation tracker
    angle_z = 0.0
    utime.sleep_ms(1000)  # Debounce period
    last_time = utime.ticks_ms()
```

---

### 4. Audio Feedback System

**File:** `music.py`

#### Mario Theme Implementation
**Composition:** 75-note melody with dynamic tempo

**Note Frequency Table:**
```python
NOTES = {
    'REST': 0,
    'C4': 262, 'D4': 294, 'E4': 330, 'F4': 349, 'G4': 392,
    'C7': 2093, 'E7': 2637, 'G7': 3136,  # High octave notes
    # ... (88 total note definitions)
}
```

**Playback Function:**
```python
def play_tone(frequency, duration, buzzer):
    if frequency == 0:  # Rest
        buzzer.duty_u16(0)
        time.sleep(duration)
    else:
        buzzer.freq(frequency)
        buzzer.duty_u16(32768)  # 50% duty cycle
        time.sleep(duration)
        buzzer.duty_u16(0)  # Stop
```

**Main Theme Structure:**
```python
def play_mario_main_theme(buzzer):
    melody_notes = [
        'E7', 'E7', 'REST', 'E7', 'REST', 'C7', 'E7', 'REST',
        'G7', 'REST', 'REST', 'REST', 'G6', 'REST', ...
    ]
    tempo_values = [12, 12, 12, 12, 12, 12, 12, 12, ...]

    for _ in range(PLAY_COUNT):  # Play 3 times
        for i in range(len(melody_notes)):
            note_duration_s = (1000 / tempo_values[i]) / 1000.0
            frequency = NOTES[melody_notes[i]]
            play_tone(frequency, note_duration_s, buzzer)

            # Note separation (30% of duration)
            pause = note_duration_s * 0.30
            time.sleep(pause)
```

**Performance:**
- **Total Duration:** ~8 seconds (3 loops)
- **Note Count:** 75 notes
- **Tempo:** Variable (9-12 BPM equivalent)
- **Thread:** Runs in background (non-blocking)

---

### 5. Icon Generation System

**File:** `icons.py`

#### Vector Graphics Approach
**Method:** Programmatic drawing using FrameBuffer primitives

**Icon Specifications:**
- **Resolution:** 80x48 pixels
- **Format:** Monochrome (1-bit)
- **Buffer Size:** 480 bytes each

**Example: Water Glass Icon**
```python
def configure_water_icon():
    # Glass dimensions
    TOP_Y, BOT_Y = 5, 42
    TOP_W, BOT_W = 44, 24
    WATER_LEVEL = 0.5  # 50% full

    center_x = 40
    x1_top = center_x - (TOP_W // 2)
    x2_top = center_x + (TOP_W // 2)
    x1_bot = center_x - (BOT_W // 2)
    x2_bot = center_x + (BOT_W // 2)

    # Draw glass outline (trapezoid)
    fb_glass.line(x1_top, TOP_Y, x1_bot, BOT_Y, 1)  # Left edge
    fb_glass.line(x2_top, TOP_Y, x2_bot, BOT_Y, 1)  # Right edge
    fb_glass.line(x1_bot, BOT_Y, x2_bot, BOT_Y, 1)  # Bottom

    # Fill water (gradient fill simulation)
    water_height_px = int((BOT_Y - TOP_Y) * WATER_LEVEL)
    water_surface_y = BOT_Y - water_height_px

    for y in range(BOT_Y - 1, water_surface_y, -1):
        ratio = (BOT_Y - y) / (BOT_Y - TOP_Y)
        current_half_w = (BOT_W // 2) + int((TOP_W - BOT_W) // 2 * ratio)
        fb_glass.hline(center_x - current_half_w + 1, y,
                       current_half_w * 2 - 2, 1)
```

**Other Icons:**
- **Code:** Terminal window with prompt and cursor
- **Sport:** Dumbbell (barbell with weights)
- **Language:** Overlapping translation books
- **Glasses:** Reading glasses (two lenses + bridge)

---

## API Integration

### Backend Endpoint
**Production URL:** `https://backend-1089871134307.europe-west1.run.app`

### Endpoints Used

#### 1. GET /api/v1/habits/active
**Purpose:** Fetch currently active habits for display

**Request:**
```python
response = requests.get(
    "https://backend-1089871134307.europe-west1.run.app/api/v1/habits/active"
)
```

**Response (200 OK):**
```json
{
  "habits": [
    {
      "id": 1,
      "name": "Drink Water",
      "type": "water",
      "description": "Drink 8 glasses",
      "deadline_time": "21:00",
      "frequency": "daily"
    },
    {
      "id": 2,
      "name": "Morning Exercise",
      "type": "sport",
      "description": "30 min workout",
      "deadline_time": "09:00",
      "frequency": "daily"
    }
  ]
}
```

**Implementation:**
```python
def load_active_habits():
    global active_habits
    response = requests.get(
        "https://backend-1089871134307.europe-west1.run.app/api/v1/habits/active"
    )
    content = response.content
    habits = json.loads(content)
    active_habits = habits["habits"]
```

#### 2. POST /api/v1/habits/{id}/complete
**Purpose:** Mark habit as completed

**Request:**
```python
response = requests.post(
    f"https://backend-1089871134307.europe-west1.run.app/api/v1/habits/{habit_id}/complete",
    json={}
)
```

**Response (200 OK):**
```json
{
  "message": "Habit completed successfully",
  "habit_id": 1,
  "completion_time": "2025-12-07T14:30:00Z",
  "current_streak": 5,
  "total_completions": 42
}
```

**Response (400 Bad Request):**
```json
{
  "error": "Already completed today"
}
```

**Implementation with Safety Check:**
```python
def complete_and_switch_habit():
    # NEW: Safety check for empty list
    if len(active_habits) <= 0:
        return

    habit_id = str(active_habits[active_habit_index]["id"])
    response = requests.post(
        f"https://backend-1089871134307.europe-west1.run.app/api/v1/habits/{habit_id}/complete",
        json={}
    )
    print(response.content)

    # Only remove habit on successful completion
    if response.status_code == 200:
        active_habits.pop(active_habit_index)
        switch_next_habit()
```

---

## System Workflows

### Startup Sequence

```
1. Hardware Initialization
   ├─ Configure I2C (GPIO 0,1) for gyroscope
   ├─ Configure SPI (GPIO 2-6) for display
   ├─ Configure GPIO 16,17 for buttons (PULL_UP)
   ├─ Configure PWM (GPIO 22) for buzzer
   └─ Initialize icons in framebuffers

2. Network Connection
   ├─ Try reading wlan.info file
   ├─ If exists:
   │   ├─ Parse SSID and password
   │   ├─ Connect to WiFi (10s timeout)
   │   └─ If fails → Start captive portal
   └─ If not exists → Start captive portal

3. Data Synchronization
   ├─ Load active habits from API
   └─ Display first habit (if available)

4. Sensor Calibration
   ├─ Sample gyroscope 200 times (1 second)
   ├─ Calculate Z-axis offset
   └─ Initialize rotation tracking

5. Enter Main Loop
```

### Main Loop Operation

**Loop Frequency:** ~100 Hz (10ms cycle time)

```python
while True:
    # 1. Button Handling
    if button1.value() == 0 and button2.value() == 0:
        # Both pressed: Reload habits
        display.show_loading_screen()
        load_active_habits()
        display.display_active_habit(active_habits, active_habit_index)
        angle_z = 0

    elif button1.value() == 0:
        # Previous habit
        switch_previous_habit()
        display.display_active_habit(active_habits, active_habit_index)
        utime.sleep_ms(100)  # Debounce
        angle_z = 0

    elif button2.value() == 0:
        # Next habit
        switch_next_habit()
        display.display_active_habit(active_habits, active_habit_index)
        utime.sleep_ms(100)
        angle_z = 0

    # 2. Gyroscope Reading
    current_time = utime.ticks_ms()
    dt = utime.ticks_diff(current_time, last_time) / 1000.0
    last_time = current_time

    gyro_z_raw = sensor.gyro[2]
    gyro_z_rad = gyro_z_raw - gyro_offset_raw
    gyro_z_deg = gyro_z_rad * 57.296  # rad → deg

    # Dead-zone filter
    if abs(gyro_z_deg) < 0.5:
        gyro_z_deg = 0

    # Integration
    angle_z += gyro_z_deg * dt

    # 3. Completion Detection
    if abs(angle_z) >= 160:
        print("Rotation detected!")

        # Parallel audio playback
        _thread.start_new_thread(music.play_mario_main_theme, (buzzer,))

        # Visual animation (5 loops)
        play_sui_animation()

        # API call + state update
        complete_and_switch_habit()

        # Display update
        display.display_active_habit(active_habits, active_habit_index)

        # Reset
        angle_z = 0.0
        utime.sleep_ms(1000)
        last_time = utime.ticks_ms()

    utime.sleep_ms(10)  # 100 Hz loop
```

### Habit Navigation Flow

```
Button 1 Pressed:
    → active_habit_index -= 1
    → if (index < 0): index = len(habits) - 1  // Wrap to last
    → Update display
    → Reset rotation angle

Button 2 Pressed:
    → active_habit_index += 1
    → if (index >= len(habits)): index = 0  // Wrap to first
    → Update display
    → Reset rotation angle

Both Buttons Pressed:
    → Show "Loading Habits..." message
    → GET /api/v1/habits/active
    → Parse JSON response
    → Update active_habits list
    → Display first habit
    → Reset rotation angle
```

---

## Technical Achievements

### 1. Robust WiFi Management
✅ **Automatic Fallback:** Seamless AP mode on connection failure
✅ **Persistent Storage:** Flash-based credential storage
✅ **User-Friendly Setup:** Modern responsive web interface
✅ **Network Discovery:** SSID scanning with deduplication
✅ **Validation:** 10-second connection timeout with feedback

### 2. Accurate Rotation Detection
✅ **Calibration:** 200-sample averaging eliminates bias
✅ **Integration-Based:** Converts angular velocity → angle
✅ **Drift Compensation:** Dead-zone filtering (<0.5°/s)
✅ **Threshold Detection:** 160° prevents false positives
✅ **Auto-Reset:** Angle zeroed after each event

### 3. Optimized Display System
✅ **Memory Efficiency:** Single display instance (was dual)
✅ **Icon-Based UI:** Visual habit identification
✅ **Text Truncation:** Prevents overflow (16 char limit)
✅ **Empty State Handling:** Graceful fallback message
✅ **Smooth Animations:** 200 FPS bitmap playback

### 4. Asynchronous Feedback
✅ **Non-Blocking Audio:** Threaded music playback
✅ **Visual Reward:** 55-frame celebration animation
✅ **Backend Sync:** State update only on HTTP 200
✅ **Error Handling:** Graceful degradation

### 5. Modular Architecture
✅ **Separation of Concerns:** Display, network, sensors isolated
✅ **Driver Abstraction:** Hardware code in `drivers/`
✅ **Reusable Components:** DRY principle throughout
✅ **Easy Maintenance:** Clear file structure

---

## Troubleshooting

### WiFi Connection Issues

**Problem:** Cannot connect to saved network
**Solution:**
1. Hold both buttons during startup to force reload
2. If that fails, delete `wlan.info` file and restart
3. Device will enter captive portal mode automatically

**Problem:** Captive portal not accessible
**Solution:**
1. Verify "HabCube" SSID is visible in WiFi list
2. Connect to "HabCube" (password: `habcube2115`)
3. Open browser → Should auto-redirect to configuration page
4. If no redirect, manually navigate to `http://192.168.4.1`

### Display Problems

**Problem:** OLED screen blank
**Solution:**
1. Check SPI connections (GPIO 2-6)
2. Verify CS pin is properly connected (GPIO 4)
3. Ensure 3.3V/5V power supply is stable
4. Check RST pin is not floating

**Problem:** Icons not displaying
**Solution:**
1. Verify `icons.configure_icons()` was called
2. Check habit type matches supported types
3. Ensure bitmap files exist in root directory

**Problem:** Text shows "..."
**Cause:** Habit name exceeds 16 characters (intended behavior)
**Solution:** Shorten habit name in mobile app

### Gyroscope Issues

**Problem:** Rotation not detected
**Solution:**
1. Check I2C connections (GPIO 0, 1)
2. Verify MPU-9250 I2C address is 0x68
3. Ensure device was stationary during calibration
4. Recalibrate by restarting device

**Problem:** False rotation triggers
**Solution:**
1. Increase dead-zone threshold (currently 0.5°/s)
2. Recalibrate on stable surface
3. Check for loose connections causing vibration

**Problem:** "MPU6500 not found" error
**Solution:**
1. Check I2C wiring (SDA=GPIO0, SCL=GPIO1)
2. Try different I2C address (0x69)
3. Verify sensor power supply (3.3V)

### API Communication

**Problem:** Habits not loading
**Solution:**
1. Verify WiFi connection (check IP address)
2. Test backend URL: `curl https://backend-1089871134307.europe-west1.run.app/health`
3. Check firewall/network restrictions

**Problem:** Completion not registering
**Solution:**
1. Check HTTP response code in console
2. Verify habit ID exists in backend
3. Ensure habit not already completed today
4. Check internet connectivity

**Problem:** "No active habits" message
**Cause:** No habits marked as active in backend
**Solution:** Add habits via mobile app and activate them

---

## Future Enhancements

### Hardware
- [ ] RGB LED strips for visual feedback per habit type
- [ ] Battery power with LiPo charging circuit (3.7V 2000mAh)
- [ ] Vibration motor for tactile feedback
- [ ] Ambient light sensor for auto-brightness control
- [ ] USB-C port for faster charging

### Software
- [ ] **OTA Firmware Updates:** Download new `.uf2` files via WiFi
- [ ] **Offline Mode:** Local habit caching with sync when online
- [ ] **Custom Animations:** Upload via web interface
- [ ] **Battery Monitoring:** Display charge level on OLED
- [ ] **NTP Time Sync:** Track deadline compliance
- [ ] **BLE Support:** Direct pairing with mobile app
- [ ] **Deep Sleep Mode:** Wake on button press (save battery)
- [ ] **Multi-User Support:** User profiles with habit isolation
- [ ] **Streak Recovery:** Grace period for missed habits
- [ ] **Sound Customization:** Upload custom completion sounds

### User Experience
- [ ] **Progressive Animations:** Different animations based on streak length
- [ ] **Daily Summary:** Show completion stats at end of day
- [ ] **Habit Reminders:** Buzzer alerts before deadline
- [ ] **Weather Integration:** Outdoor habit suggestions
- [ ] **Achievement Badges:** Unlock milestones (7-day, 30-day streaks)

---

## Performance Metrics

### Response Times
| Operation | Time | Notes |
|---|---|---|
| WiFi Connect | 2-5s | Depends on router |
| API Request (GET) | 200-500ms | Cloud Run latency |
| API Request (POST) | 300-600ms | Includes DB write |
| Display Update | 16ms | ~60 FPS |
| Animation Frame | 5ms | 200 FPS |
| Gyro Calibration | 1s | 200 samples |
| Button Debounce | 100ms | Prevents double-press |

### Memory Usage
- **Flash (Program):** ~45 KB (15% of 2 MB)
- **SRAM (Runtime):** ~28 KB (11% of 264 KB)
- **Icon Buffers:** 2.4 KB (5 icons × 480 bytes)
- **Animation Buffer:** 1 KB (reused per frame)

---

## Code Quality Best Practices

### ✅ Implemented

1. **Error Handling:** Try/except for network and file operations
2. **Type Consistency:** Proper variable initialization
3. **Constants:** Magic numbers avoided (`HOW_MANY_ANIMATION_PLAY = 5`)
4. **Documentation:** Clear comments for complex algorithms
5. **DRY Principle:** Reusable display functions
6. **Safety Checks:** Empty list validation before access
7. **Resource Cleanup:** Socket closure, display clearing
8. **Debouncing:** 100ms delay on button press
9. **Thread Safety:** Audio playback in separate thread

### Hardware Interface
✅ Pull-up resistors on buttons
✅ Proper SPI baudrate (1 MHz)
✅ PWM duty cycle management (0-65535)
✅ I2C bypass register manipulation

### Network Programming
✅ RESTful API design
✅ JSON parsing and validation
✅ Status code checking before state changes
✅ Socket timeout configuration

---

## Credits & Licenses

### Third-Party Libraries

**MPU-9250 Driver**
- Author: Mika Tuupola (@tuupola)
- Repository: [micropython-mpu9250](https://github.com/tuupola/micropython-mpu9250)
- License: MIT
- Version: 0.4.0

**SH1106 OLED Driver**
- Authors: Radomir Dopieralski, Robert Hammelrath, Tim Weber
- License: MIT

**Captive Portal**
- Inspiration: [amora-labs/micropython-captive-portal](https://github.com/amora-labs/micropython-captive-portal)

### Development Team

| Name | Role | Contributions |
|---|---|---|
| **Patryk Kurek** | Hardware Lead & Tech Manager | Electronic schematic, component assembly, OBSW development, captive portal, documentation |
| **Piotr Ziobrowski** | Embedded Developer | 3D cube design, WiFi implementation, testing |
| **Aleksy Dąda** | Backend Lead | API development, Google Cloud deployment, Docker |
| **Paweł Klocek** | Database Architect | Database schema, backend endpoints, documentation |
| **Szymon Domagała** | Frontend Lead | Mobile app UI/UX, React Native implementation |

---

## Technical Specifications Summary

| Component | Model | Interface | GPIO/Address | Current Draw | Purpose |
|---|---|---|---|---|---|
| **MCU** | Raspberry Pi Pico WH | - | - | 80-100mA | Main controller |
| **Gyroscope** | MPU-9250 9DoF | I2C | SDA=0, SCL=1 | 3.5mA | Rotation detection |
| **Display** | SH1106 OLED 128x64 | SPI0 | CS=4, DC=5, RST=6 | 20mA | Visual output |
| **Button 1** | Membrane Switch | GPIO | Pin 17 (PULL_UP) | <1mA | Previous habit |
| **Button 2** | Membrane Switch | GPIO | Pin 16 (PULL_UP) | <1mA | Next habit |
| **Buzzer** | Grove Passive Buzzer | PWM | Pin 22 | 30mA (peak) | Audio feedback |
| **WiFi** | CYW43439 | Built-in | - | 80mA (active) | Network connectivity |

**Total Power:** 0.55-0.78W (typical-peak)

---

## Appendix: File Manifest

```
obsw/
├── main.py                    # 187 lines - Main application
├── captive/captive.py         # 211 lines - WiFi configuration
├── display/display.py         # 109 lines - Display management
├── music.py                   #  56 lines - Audio playback
├── icons.py                   #  97 lines - Icon generation
├── drivers/gyroscope/
│   ├── mpu9250.py            # 101 lines - 9DoF sensor
│   ├── mpu6500.py            # 226 lines - Gyro/Accel
│   └── ak8963.py             # 207 lines - Magnetometer
├── drivers/oled/
│   └── sh1106.py             # 319 lines - OLED driver
└── gif/                       # 55 BMP files (128x64 @1-bit)
    └── resized_*.bmp          # Total: ~50 KB

Total OBSW Lines: ~1,513 lines of MicroPython
```

---

**Document Version:** 2.0
**Last Updated:** December 7, 2025
**Project Status:** Production Ready
**Next Review:** January 2026

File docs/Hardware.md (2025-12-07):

# Hardware

Board: [Raspberry pi pico WH](https://botland.com.pl/moduly-i-zestawy-do-raspberry-pi-pico/21575-raspberry-pi-pico-wh-rp2040-arm-cortex-m0-cyw43439-wifi-ze-zlaczami-5056561800196.html)
Gyroscope: SparkFun MPU-9250 9DoF(borrowed)
LCDs: OLED SCREEN 1,3" I2C x2(borrowed) 
Switches: [2xMembrane switch](https://botland.com.pl/klawiatury-arduino/17118-klawiatura-membranowa-1-szary-klawisz-samoprzylepna-5904422326920.html)
Board: https://datasheets.raspberrypi.com/rp2040/rp2040-datasheet.pdf, https://datasheets.raspberrypi.com/picow/pico-w-datasheet.pdf
Gyroscope:  https://botland.com.pl/index.php?controller=attachment&id_attachment=2716
Switches: https://botland.com.pl/klawiatury-arduino/17118-klawiatura-membranowa-1-szary-klawisz-samoprzylepna-5904422326920.html
Passive Buzzer: https://files.seeedstudio.com/products/107020109/document/MLT_8530_datasheet.pdf
LCDs: https://sklep.msalamon.pl/download/127859/?tmstv=1756190702

## Useful links:

[Guide how to connect and run screen](https://sklep.msalamon.pl/blog/instrukcja-uruchomienia-wyswietlacza-oled-128x64-sh1106/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)
[Guide creating bitmaps from online image generator](https://sklep.msalamon.pl/blog/instrukcja-tworzenia-bitmap-z-obrazow-na-bazie-generatora-online/)

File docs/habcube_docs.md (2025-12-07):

# Spis Treści

1. [Zespół](#zespół)
2. [Hardware & OBSW](#habcube---dokumentacja-hardware--obsw)
3. [Baza Danych](#baza-danych)
4. [Backend (API)](#habcube---dokumentacja-backendu)
5. [Aplikacja Mobilna](#dokumentacja-aplikacji-mobilnej-habcube)
6. [Projekt 3D i Obudowa](#dokumentacja-projektu-3d-i-obudowy---habcube)

---
# HabCube

## Opis
"Inteligentna Kostka" to urządzenie IoT, które wspiera użytkowników w kształtowaniu i utrzymywaniu codziennych nawyków. Nawyki definiowane są w aplikacji mobilnej, która umożliwia ich konfigurację oraz prezentację statystyk dotyczących postępów.

## Wstęp
Celem tego projektu jest stworzenie kompletnego systemu Internetu Rzeczy (IoT) zaprojektowanego do działania w sieci lokalnej. System łączy warstwę sprzętową (fizyczną kostkę) z aplikacją mobilną, która pozwala użytkownikom definiować, konfigurować i śledzić swoje nawyki, a także przeglądać statystyki swoich osiągnięć.

Projekt integruje wiedzę z zakresu elektroniki, informatyki, programowania sieciowego oraz inżynierii systemów wbudowanych. Prace obejmują zarówno warstwę sprzętową (projekt i wykonanie kostki), jak i warstwę programową (komunikacja serwerowa, backend, mobilny interfejs użytkownika oraz ogólna integracja systemu).

## Cele Projektu

### Cele Ogólne
- Stworzenie w pełni funkcjonalnego systemu IoT działającego w sieci lokalnej.
- Osiągnięcie wysokiej skuteczności w pomaganiu użytkownikom w budowaniu i utrzymywaniu pozytywnych nawyków.
- Zaprojektowanie systemu zwiększającego motywację i zaangażowanie użytkownika w proces samodoskonalenia.
- Opracowanie produktu końcowego, który realnie poprawia jakość życia użytkowników poprzez wsparcie w osiąganiu celów związanych z nawykami.

### Cele Edukacyjne
- Zrozumienie praktycznych aspektów budowania kompletnych systemów IoT (od podstaw do wdrożenia).
- Nauka integracji sprzętu i oprogramowania w jeden spójny system.
- Rozwój umiejętności pracy zespołowej i zarządzania projektem.
- Zdobycie doświadczenia w planowaniu, wdrażaniu, testowaniu i dokumentowaniu złożonego projektu technicznego.
- Poznanie mechanizmów motywacyjnych najskuteczniejszych w kształtowaniu nawyków oraz projektowanie angażujących i intuicyjnych interakcji z użytkownikiem.

## Zakres Projektu

### Kluczowe Funkcjonalności
- **Konfiguracja Nawyków**: Definiowanie i zarządzanie nawykami za pośrednictwem aplikacji mobilnej.
- **Śledzenie Postępów**: Monitorowanie postępów użytkownika i prezentowanie ich w formie statystyk.
- **Informacja Zwrotna i Motywacja**: Dostarczanie użytkownikom wizualnych, dźwiękowych i świetlnych "zastrzyków dopaminy" w celu wzmocnienia pozytywnych działań.

### Architektura Systemu
System składa się z trzech głównych komponentów:
1.  **Inteligentna Kostka**: Fizyczne urządzenie oparte na mikrokontrolerze, stanowiące główny punkt interakcji z użytkownikiem.
2.  **Serwer Centralny**: Usługa backendowa odpowiedzialna za obsługę komunikacji z kostką, przetwarzanie danych i przechowywanie statystyk użytkownika.
3.  **Aplikacja Mobilna**: Interfejs użytkownika służący do konfiguracji kostki, definiowania nawyków i przeglądania danych o postępach.

Wszystkie komponenty komunikują się ze sobą za pośrednictwem lokalnej sieci Wi-Fi.
# Zespół

| Imię i nazwisko | Rola | Zakres obowiązków |
|---|---|---|
| **Patryk Kurek** | Hardware Lead & Tech Manager | Schematy elektroniczne, montaż podzespołów, rozwój oprogramowania wbudowanego (OBSW), captive portal, dokumentacja |
| **Piotr Ziobrowski** | Embedded Developer | Projekt obudowy 3D, implementacja Wi-Fi, testowanie |
| **Aleksy Dąda** | Backend Lead | Rozwój API, wdrożenie (deployment) w Google Cloud, Docker |
| **Paweł Klocek** | Backend Architect | Schemat bazy danych, endpointy backendowe, dokumentacja |
| **Szymon Domagała** | Frontend Lead | UI/UX aplikacji mobilnej, implementacja w React Native |

---

# HabCube - Dokumentacja Hardware & OBSW 

> **Project:** Intelligent Habit Tracking Cube
> **Version:** 2.0
> **Last Updated:** December 7, 2025
> **Authors:** Patryk Kurek, Piotr Ziobrowski

## Przegląd systemu
HabCube to urządzenie IoT oparte na mikrokontrolerze Raspberry Pi Pico WH. Urządzenie integruje czujniki ruchu (IMU), podwójny interfejs wizualny (OLED) oraz systemy interakcji użytkownika (przyciski, buzzer) w kompaktowej obudowie 3D. Całość zasilana jest napięciem 5V.

## Komponenty Sprzętowe

### Mikrokontroler

**Płytka:** [Raspberry Pi Pico WH](https://botland.com.pl/moduly-i-zestawy-do-raspberry-pi-pico/21575-raspberry-pi-pico-wh-rp2040-arm-cortex-m0-cyw43439-wifi-ze-zlaczami-5056561800196.html)

**Specyfikacja:**
- **Procesor:** Dwurdzeniowy ARM Cortex-M0+ (RP2040)
- **Taktowanie:** Do 133 MHz
- **Pamięć:** 264 KB SRAM, 2 MB Flash
- **WiFi:** Układ bezprzewodowy CYW43439 2.4GHz 802.11n
- **GPIO:** 26 pinów wielofunkcyjnych z wlutowanymi złączami (headers)
- **Interfejsy:** 2x UART, 2x SPI, 2x I2C, 16x kanałów PWM

**Dokumentacja techniczna (Datasheets):**
- [RP2040 Technical Reference](https://datasheets.raspberrypi.com/rp2040/rp2040-datasheet.pdf)
- [Pico W Datasheet](https://datasheets.raspberrypi.com/picow/pico-w-datasheet.pdf)

---

### Czujniki i Peryferia

#### Czujnik Ruchu (IMU)
**Model:** SparkFun MPU-9250 9DoF (9 stopni swobody)

**Specyfikacja:**
- **Żyroskop:** 3-osiowy, ±250 do ±2000 °/s
- **Akcelerometr:** 3-osiowy, ±2g do ±16g
- **Magnetometr:** 3-osiowy kompas AK8963
- **Interfejs:** I2C (adres 0x68)
- **Rozdzielczość:** 16-bit ADC
- **Częstotliwość odświeżania:** Do 8 kHz (gyro/accel)

**Przeznaczenie:** Wykrywa obrót kostki w celu wyzwolenia zatwierdzenia nawyku.

**Dokumentacja:** [Specyfikacja MPU-9250](https://botland.com.pl/index.php?controller=attachment&id_attachment=2716)

---

#### System Wyświetlania
**Model:** Ekran OLED 1.3" (128x64 pikseli) - Sterownik SH1106

**Specyfikacja:**
- **Rozdzielczość:** 128x64 pikseli (monochromatyczny)
- **Układ sterujący:** SH1106
- **Interfejs:** SPI (4-przewodowy)
- **Napięcie:** 3.3V - 5V
- **Kąt widzenia:** >160°
- **Kontrast:** Regulowany programowo

**Konfiguracja:** Pojedynczy wyświetlacz (zoptymalizowany względem poprzedniej konfiguracji z dwoma ekranami).

**Przeznaczenie:** Wyświetlanie ikon nawyków, nazw, komunikatów statusu oraz animacji.

**Zasoby:**
- [Nota katalogowa SH1106](https://sklep.msalamon.pl/download/127859/?tmstv=1756190702)
- [Instrukcja uruchomienia](https://sklep.msalamon.pl/blog/instrukcja-uruchomienia-wyswietlacza-oled-128x64-sh1106/)
- [Instrukcja generatora bitmap](https://sklep.msalamon.pl/blog/instrukcja-tworzenia-bitmap-z-obrazow-na-bazie-generatora-online/)

---

#### Interfejs Użytkownika
**Model:** [2x Przycisk Membranowy (Samoprzylepny)](https://botland.com.pl/klawiatury-arduino/17118-klawiatura-membranowa-1-szary-klawisz-samoprzylepna-5904422326920.html)

**Specyfikacja:**
- **Typ:** Klawiatura membranowa jednoprzyciskowa
- **Montaż:** Podkład samoprzylepny
- **Kolor:** Szary
- **Działanie:** Sygnał dotykowy (tactile feedback)
- **Interfejs:** Proste zwarcie przełącznika (aktywny stanem niskim)

**Funkcje Przycisków:**
- **Przycisk 1 (GPIO 17):** Przejście do poprzedniego nawyku
- **Przycisk 2 (GPIO 16):** Przejście do następnego nawyku
- **Oba wciśnięte:** Przeładowanie aktywnych nawyków z serwera

**Link do produktu:** [Klawiatura Membranowa](https://botland.com.pl/klawiatury-arduino/17118-klawiatura-membranowa-1-szary-klawisz-samoprzylepna-5904422326920.html)

---

#### Sygnalizacja Dźwiękowa (Audio Feedback)
**Model:** Buzzer Pasywny Grove (Seeedstudio 107020109)

**Specyfikacja:**
- **Typ:** Pasywny buzzer piezoelektryczny
- **Zakres częstotliwości:** 2kHz - 5kHz
- **Napięcie pracy:** 3.3V - 5V
- **Ciśnienie akustyczne:** ≥85dB @ 10cm
- **Częstotliwość rezonansowa:** 2.7kHz ± 300Hz

**Przeznaczenie:** Odtwarzanie motywu muzycznego Mario po wykonaniu nawyku (melodie sterowane PWM).

**Dokumentacja:** [Buzzer MLT-8530](https://files.seeedstudio.com/products/107020109/document/MLT_8530_datasheet.pdf)

---

### Przypisanie Pinów GPIO

#### Wyświetlacz SPI (OLED)
| Funkcja | Pin GPIO | Opis |
|---|---|---|
| SCK | 2 | Zegar SPI |
| MOSI | 3 | Master Out Slave In (Dane) |
| CS | 4 | Chip Select (aktywny niski) |
| DC | 5 | Wybór Dane/Komenda |
| RST | 6 | Reset Sprzętowy |
| **Magistrala** | SPI0 | Sprzętowy kontroler SPI |

#### Żyroskop I2C (MPU-9250)
| Funkcja | Pin GPIO | Opis |
|---|---|---|
| SDA | 0 | Linia Danych I2C |
| SCL | 1 | Linia Zegarowa I2C |
| **Magistrala** | I2C0 | Sprzętowy kontroler I2C |
| **Adres** | 0x68 | Domyślny adres I2C |

#### Interfejs Użytkownika
| Komponent | Pin GPIO | Konfiguracja |
|---|---|---|
| Przycisk 1 | 17 | WEJŚCIE z PULL_UP |
| Przycisk 2 | 16 | WEJŚCIE z PULL_UP |
| Buzzer (PWM) | 22 | Wyjście PWM |

**Uwaga:** Przyciski są aktywne w stanie niskim (wciśnięty = 0, zwolniony = 1).

---

### Specyfikacja Zasilania

**Wejście:** 5V USB-C (standard Raspberry Pi Pico WH)

**Pobór Prądu:**
- **Pico W (WiFi aktywne):** 80-100 mA
- **Wyświetlacz OLED:** 20 mA
- **MPU-9250:** 3.5 mA (wszystkie czujniki)
- **Buzzer (Aktywny):** 30 mA (szczytowo)
- **Razem (Typowo):** ~110-125 mA @ 5V = **0.55-0.62W**
- **Razem (Szczytowo):** ~155 mA @ 5V = **0.78W** (podczas odtwarzania dźwięku)

---

## Schemat Elektroniczny

### Lokalizacja plików schematu
- **PDF:** `docs/schema/Schematic_IOT2025_2025-10-29.pdf`
- **PNG:** `docs/schema/Schematic_IOT2025_2025-10-29.png`
- **SVG:** `docs/schema/Schematic_IOT2025_2025-10-29.svg`

### Podsumowanie połączeń

```text
Raspberry Pi Pico WH (RP2040)
    │
    ├─── I2C0 (GPIO 0,1) ────► Żyroskop MPU-9250
    │
    ├─── SPI0 (GPIO 2,3,4,5,6) ────► Wyświetlacz OLED SH1106
    │
    ├─── GPIO 16 ────► Przycisk 2 (Następny Nawyk)
    │
    ├─── GPIO 17 ────► Przycisk 1 (Poprzedni Nawyk)
    │
    ├─── GPIO 22 (PWM) ────► Buzzer Pasywny
    │
    └─── WiFi (CYW43439) ────► Backend w Chmurze (Google Cloud Run)
```
---

### Struktura Projektu Hardware

```
obsw/
├── main.py                         # Application entry point & main loop
├── captive/
│   └── captive.py                 # WiFi captive portal system
├── display/
│   └── display.py                 # OLED display management
├── drivers/
│   ├── gyroscope/
│   │   ├── mpu9250.py            # Main 9DoF sensor driver
│   │   ├── mpu6500.py            # Gyro/Accel component
│   │   └── ak8963.py             # Magnetometer component
│   └── oled/
│       ├── sh1106.py             # SH1106 OLED driver (SPI/I2C)
│       └── sh1106.pyi            # Type hints
├── music.py                       # Audio playback (Mario theme)
├── icons.py                       # Habit icon generator (vector graphics)
├── gif/                           # Animation frames (55 BMP files)
│   ├── resized_0.bmp
│   ├── resized_1.bmp
│   └── ... (resized_54.bmp)
├── clear.py                       # Utility script
└── wlan.info                      # WiFi credentials (auto-generated)
```

---
## Kluczowe Systemy (Core Systems)

### 1. Konfiguracja WiFi (Captive Portal)

**Plik:** `captive/captive.py`

#### Cel
Umożliwia bezproblemową konfigurację WiFi, gdy urządzenie nie może połączyć się przy użyciu zapisanych danych uwierzytelniających. Tworzy punkt dostępu (AP) z interfejsem webowym do konfiguracji sieci.

#### Funkcje
- Automatyczne przejście w tryb AP w przypadku błędu połączenia
- Skanowanie sieci z deduplikacją SSID
- Responsywny interfejs webowy HTML5
- Walidacja i zapisywanie danych logowania
- Automatyczny restart po udanym nawiązaniu połączenia

#### Szczegóły Implementacji
**Access Point Configuration:**
```python
ap.config(essid="HabCube", password="habcube2115")
```

**Network Scanning:**
```python
def fetch_networks(wlan):
    scan_results = wlan.scan()
    found_ssids = set()  # Deduplication
    for result in scan_results:
        ssid = result[0].decode('utf-8')
        if ssid and ssid not in found_ssids:
            found_ssids.add(ssid)
            ssid_options += f'<option value="{ssid}">{ssid}</option>'
    return ssid_options
```

**Web Server:**
- **Port:** 80 (HTTP)
- **Socket Timeout:** 2 seconds
- **Method:** POST for credential submission
- **Persistent Storage:** `wlan.info` file (space-separated SSID and password)

**HTML Interface Highlights:**
- Modern CSS3 with flexbox layout
- Mobile-responsive (viewport meta tag)
- Dropdown network selector (auto-populated)
- Password input with type="password"
- Visual feedback during connection attempt

**Przepływ połączenia:**
```
1. Użytkownik łączy się z siecią WiFi "HabCube"
2. Otwiera przeglądarkę → Wykrycie Captive Portal
3. Wybiera sieć docelową z listy rozwijanej
4. Wpisuje hasło
5. Klika "Połącz"
6. Urządzenie weryfikuje dane (timeout 10s)
7. Sukces: Zapisuje dane do wlan.info → Wykonuje restart
8. Błąd: Wyświetla komunikat "Wrong Credentials!" (Błędne dane)
```
### 2. System Zarządzania Wyświetlaczem

**Plik:** `display/display.py`

#### Aktualizacja Architektury
**Optymalizacja:** Przeprowadzono refaktoryzację z obsługi dwóch wyświetlaczy na **pojedynczą instancję wyświetlacza** w celu poprawy wydajności i zmniejszenia zużycia pamięci.

**Inicjalizacja Wyświetlacza:**
```python
spi_oled1 = SPI(0, baudrate=1000000, sck=Pin(2), mosi=Pin(3))
cs_oled1 = Pin(4, Pin.OUT, value=1)
dc_oled1 = Pin(5, Pin.OUT)
rst_oled1 = Pin(6, Pin.OUT)

displays = SH1106_SPI(128, 64, spi_oled1, dc_oled1, rst_oled1, cs_oled1,
                      rotate=0, delay=0)
```

#### Key Functions
```python 
def display_text_centered(text):
    displays.fill(0)

    MAX_CHARS_PER_LINE = 16
    lines = [text[i:i+MAX_CHARS_PER_LINE]
             for i in range(0, len(text), MAX_CHARS_PER_LINE)]

    total_text_height = len(lines) * 8  
    y_start = (64 - total_text_height) //

    for i, line in enumerate(lines):
        x_pos = (128 - len(line) * 8) // 2  
        y_pos = y_start + (i * 8)
        displays.text(line, x_pos, y_pos, 1)

    displays.show()
```
Zastosowanie:
- Status połączenia WiFi
- Komunikaty błędów

- Ekrany ładowania

##### 2. Wyświetlanie aktywnych nawyków

```python
def display_active_habit(active_habits, active_habit_index):
    # Safety check for empty list
    if len(active_habits) <= 0:
        display_text_centered("No active habits try adding one in mobile app")
        return

    habit_name = active_habits[active_habit_index]["name"]
    displays.fill(0)

    # Icon positioning (80x48px icons)
    x_icon = (128 - 80) // 2  # Center horizontally

    # Icon selection based on habit type
    habit_type = active_habits[active_habit_index]["type"]
    if habit_type == "water":
        displays.blit(icons.fb_glass, x_icon, 0)
    elif habit_type == "sport":
        displays.blit(icons.fb_sport, x_icon, 0)
    elif habit_type == "language":
        displays.blit(icons.fb_lang, x_icon, 0)
    elif habit_type == "read":
        displays.blit(icons.fb_glasses, x_icon, 0)
    elif habit_type == "code":
        displays.blit(icons.fb_code, x_icon, 0)

    # Text truncation (NEW: prevents overflow)
    max_chars = 16
    if len(habit_name) > max_chars:
        habit_name = habit_name[:max_chars - 3] + "..."

    # Centered text below icon
    text_length = len(habit_name) * 8
    x_text = max(0, (128 - text_length) // 2)
    displays.text(habit_name, x_text, 52, 1)
    displays.show()
```

**Wspierane typy nawyków:**
| Typ | Ikona | Opis |
|---|---|---|
| `water` | Glass | Przypomnienie o piciu wody |
| `sport` | Dumbbell | Uprawianie sportu |
| `language` | Book/Flag | Nauka języków |
| `read` | Glasses | Nawyk czytania |
| `code` | Terminal | Nauka programowaia |

##### 3. Wyświetlenie Animacji
```python
def play_animation(frame_delay_ms=5):
    
    frame_number = 1
    while True:
        filename = f"resized_{frame_number}.bmp"
        try:
            with open(filename, "rb") as f:
                f.seek(10)  
                data_offset = int.from_bytes(f.read(4), "little")
                f.seek(data_offset)
                buffer = f.read()

                fb = framebuf.FrameBuffer(bytearray(buffer), 128, 64,
                                         framebuf.MONO_HLSB)

                displays.fill(0)
                displays.blit(fb, 0, 0)
                displays.show()

                utime.sleep_ms(frame_delay_ms)
                frame_number += 1
        except OSError:
            break  
```

**Szczegóły animacji:**
- **Frame Count:** 55 frames
- **Resolution:** 128x64 monochrome
- **Format:** Windows BMP (1-bit)
- **Frame Rate:** 200 FPS (5ms delay)
- **Total Duration:** ~275ms per loop
- **Trigger:** Habit completion celebration

### 3. Gyroscope-Based Rotation Detection

**File:** `main.py` (lines 91-99, 128-183)

#### Algorytm Kalibracji
**Cel:** Wyeliminowanie odchylenia i dryftu czujnika, aby zapewnić dokładne śledzenie obrotu kostki

```python
def calibrate_gyro(samples=200):
    """
    Averages 200 gyroscope readings to calculate Z-axis offset.
    Must be performed with device stationary.
    """
    print("Calibrate gyroscope...")
    sum_z = 0
    for _ in range(samples):
        sum_z += sensor.gyro[2]  # Z-axis (vertical rotation)
        utime.sleep_ms(5)

    offset_z = sum_z / samples
    print(f"Calibrated gyroscope. Offset Z: {offset_z}")
    return offset_z
```

**Parametry Kalibracji:**
- **Liczba próbek:** 200
- **Częstotliwość próbkowania:** 200 Hz (interwał 5 ms)
- **Całkowity czas:** 1 sekunda
- **Cel:** Eliminacja statycznego przesunięcia (bias) wynikającego z tolerancji produkcyjnych

#### Integracja z obrotem

```python
# Main loop (runs at ~100 Hz)
current_time = utime.ticks_ms()
dt = utime.ticks_diff(current_time, last_time) / 1000.0  # Time delta in seconds
last_time = current_time

gyro_z_raw = sensor.gyro[2]  # Read Z-axis gyro (rad/s)

# Apply calibration offset
gyro_z_rad = gyro_z_raw - gyro_offset_raw

# Convert to degrees/second
gyro_z_deg = gyro_z_rad * 57.296  # 180/π

# Dead-zone filtering (eliminate drift from micro-vibrations)
if abs(gyro_z_deg) < 0.5:
    gyro_z_deg = 0

# Integration: angle = angle + angular_velocity * time
angle_z += gyro_z_deg * dt
```

**Parametery:**
- **Dead Zone:** 0.5 °/s (zapobiega fałszywym wynikom)
- **Threshold:** obrót o 160°
- **Direction:** dwukierunkowy (|angle| >= 160)

#### Wykonany nawyk
```python
if abs(angle_z) >= 160:
    print("Rotation detected!")

    # Non-blocking audio (separate thread)
    _thread.start_new_thread(music.play_mario_main_theme, (buzzer,))

    # Visual feedback (5 loops of 55-frame animation)
    play_sui_animation()

    # Backend API call
    complete_and_switch_habit()

    # Update display
    display.display_active_habit(active_habits, active_habit_index)

    # Reset rotation tracker
    angle_z = 0.0
    utime.sleep_ms(1000)  # Debounce period
    last_time = utime.ticks_ms()
```

### 4. Audio Feedback System

**Plik:** `music.py`

#### Implementacja Mario Theme
**Kompozycja:** 75-nutowa melodia w dynamicznym tempie

**Tabela częstotliwości:**
```python
NOTES = {
    'REST': 0,
    'C4': 262, 'D4': 294, 'E4': 330, 'F4': 349, 'G4': 392,
    'C7': 2093, 'E7': 2637, 'G7': 3136,  # High octave notes
    # ... (88 total note definitions)
}
```

**Funkcja odgrywania muzyki:**
```python
def play_tone(frequency, duration, buzzer):
    if frequency == 0:  # Rest
        buzzer.duty_u16(0)
        time.sleep(duration)
    else:
        buzzer.freq(frequency)
        buzzer.duty_u16(32768)  # 50% duty cycle
        time.sleep(duration)
        buzzer.duty_u16(0)  # Stop
```

**Struktura Main Theme:**
```python
def play_mario_main_theme(buzzer):
    melody_notes = [
        'E7', 'E7', 'REST', 'E7', 'REST', 'C7', 'E7', 'REST',
        'G7', 'REST', 'REST', 'REST', 'G6', 'REST', ...
    ]
    tempo_values = [12, 12, 12, 12, 12, 12, 12, 12, ...]

    for _ in range(PLAY_COUNT):  # Play 3 times
        for i in range(len(melody_notes)):
            note_duration_s = (1000 / tempo_values[i]) / 1000.0
            frequency = NOTES[melody_notes[i]]
            play_tone(frequency, note_duration_s, buzzer)

            # Note separation (30% of duration)
            pause = note_duration_s * 0.30
            time.sleep(pause)
```

**Wykonanie:**
- **Czas trwania:** ~8 seconds (3 loops)
- **Liczba nut:** 75 
- **Tempo:** Zmienne (9-12 BPM)
- **Wątek:** Działa w tle (nioe blokuje)

---

### 5. System Generowania Ikon

**File:** `icons.py`

#### Generowanie Grafiki Wektorowej
**Metoda:** Rysowanie programowe z wykorzystaniem FrameBuffer primitives

**Specyfikacja ikon:**
- **Rozdzielczość:** 80x48 pikseli
- **Format:** Monochromatyczny (1 bit)
- **Rozmiar bufora:** 480 bajtów każdy

**Przykład: Ikona szklanki**
```python
def configure_water_icon():
    # Glass dimensions
    TOP_Y, BOT_Y = 5, 42
    TOP_W, BOT_W = 44, 24
    WATER_LEVEL = 0.5  # 50% full

    center_x = 40
    x1_top = center_x - (TOP_W // 2)
    x2_top = center_x + (TOP_W // 2)
    x1_bot = center_x - (BOT_W // 2)
    x2_bot = center_x + (BOT_W // 2)

    # Draw glass outline (trapezoid)
    fb_glass.line(x1_top, TOP_Y, x1_bot, BOT_Y, 1)  # Left edge
    fb_glass.line(x2_top, TOP_Y, x2_bot, BOT_Y, 1)  # Right edge
    fb_glass.line(x1_bot, BOT_Y, x2_bot, BOT_Y, 1)  # Bottom

    # Fill water (gradient fill simulation)
    water_height_px = int((BOT_Y - TOP_Y) * WATER_LEVEL)
    water_surface_y = BOT_Y - water_height_px

    for y in range(BOT_Y - 1, water_surface_y, -1):
        ratio = (BOT_Y - y) / (BOT_Y - TOP_Y)
        current_half_w = (BOT_W // 2) + int((TOP_W - BOT_W) // 2 * ratio)
        fb_glass.hline(center_x - current_half_w + 1, y,
                       current_half_w * 2 - 2, 1)
```

**Przykłady innych ikon:**
- **Kod:** Okno terminala z monitem i kursorem
- **Sport:** Hantle (sztanga z ciężarkami)
- **Język:** Pokrywające się książki z tłumaczeniami
- **Okulary:** Okulary do czytania (dwie soczewki + mostek)

---
---

## Integracja API 

### Backend Endpoint
**URL:** `https://backend-1089871134307.europe-west1.run.app`

### Użyte Endpointy

#### 1. GET /api/v1/habits/active
**Cel:** Wyświetlenie aktualnie aktywnych nawyków

**Request:**
```python
response = requests.get(
    "https://backend-1089871134307.europe-west1.run.app/api/v1/habits/active"
)
```

**Response (200 OK):**
```json
{
  "habits": [
    {
      "id": 1,
      "name": "Drink Water",
      "type": "water",
      "description": "Drink 8 glasses",
      "deadline_time": "21:00",
      "frequency": "daily"
    },
    {
      "id": 2,
      "name": "Morning Exercise",
      "type": "sport",
      "description": "30 min workout",
      "deadline_time": "09:00",
      "frequency": "daily"
    }
  ]
}
```

**Implementacja:**
```python
def load_active_habits():
    global active_habits
    response = requests.get(
        "https://backend-1089871134307.europe-west1.run.app/api/v1/habits/active"
    )
    content = response.content
    habits = json.loads(content)
    active_habits = habits["habits"]
```

#### 2. POST /api/v1/habits/{id}/complete
**Cel:** Ustawienie nawyku jako wykonany

**Request:**
```python
response = requests.post(
    f"https://backend-1089871134307.europe-west1.run.app/api/v1/habits/{habit_id}/complete",
    json={}
)
```

**Response (200 OK):**
```json
{
  "message": "Habit completed successfully",
  "habit_id": 1,
  "completion_time": "2025-12-07T14:30:00Z",
  "current_streak": 5,
  "total_completions": 42
}
```

**Response (400 Bad Request):**
```json
{
  "error": "Already completed today"
}
```

**Implementacja z kontrolą:**
```python
def complete_and_switch_habit():
    # NEW: Safety check for empty list
    if len(active_habits) <= 0:
        return

    habit_id = str(active_habits[active_habit_index]["id"])
    response = requests.post(
        f"https://backend-1089871134307.europe-west1.run.app/api/v1/habits/{habit_id}/complete",
        json={}
    )
    print(response.content)

    # Only remove habit on successful completion
    if response.status_code == 200:
        active_habits.pop(active_habit_index)
        switch_next_habit()
```

---

## Przepływ systemu 

### Sekwencja uruchomienia

```
1. Inicjalizacja 
   ├─ Konfiguracja I2C (GPIO 0,1) dla żyroskopu
   ├─ Konfiguracja SPI (GPIO 2-6) dla wyświetlacza
   ├─ Konfiguracja GPIO 16,17 dla przycisków (PULL_UP)
   ├─ Konfiguracja PWM (GPIO 22) dla buzzera
   └─ Inicjalizacja ikon w buforach ramki (framebuffers)

2. Połączenie Sieciowe
   ├─ Próba odczytu pliku wlan.info
   ├─ Jeśli istnieje:
   │   ├─ Parsowanie SSID i hasła
   │   ├─ Łączenie z WiFi (timeout 10s)
   │   └─ Jeśli błąd → Uruchomienie Captive Portal
   └─ Jeśli nie istnieje → Uruchomienie Captive Portal

3. Synchronizacja Danych
   ├─ Pobranie aktywnych nawyków z API
   └─ Wyświetlenie pierwszego nawyku (jeśli dostępny)

4. Kalibracja Czujników
   ├─ Próbkowanie żyroskopu 200 razy (1 sekunda)
   ├─ Obliczenie offsetu osi Z
   └─ Inicjalizacja śledzenia obrotu

5. Wejście do Głównej Pętli
```

### Operacja głownej pętli systemu

**Loop Frequency:** ~100 Hz (10ms cycle time)

```python
while True:
    # 1. Button Handling
    if button1.value() == 0 and button2.value() == 0:
        # Both pressed: Reload habits
        display.show_loading_screen()
        load_active_habits()
        display.display_active_habit(active_habits, active_habit_index)
        angle_z = 0

    elif button1.value() == 0:
        # Previous habit
        switch_previous_habit()
        display.display_active_habit(active_habits, active_habit_index)
        utime.sleep_ms(100)  # Debounce
        angle_z = 0

    elif button2.value() == 0:
        # Next habit
        switch_next_habit()
        display.display_active_habit(active_habits, active_habit_index)
        utime.sleep_ms(100)
        angle_z = 0

    # 2. Gyroscope Reading
    current_time = utime.ticks_ms()
    dt = utime.ticks_diff(current_time, last_time) / 1000.0
    last_time = current_time

    gyro_z_raw = sensor.gyro[2]
    gyro_z_rad = gyro_z_raw - gyro_offset_raw
    gyro_z_deg = gyro_z_rad * 57.296  # rad → deg

    # Dead-zone filter
    if abs(gyro_z_deg) < 0.5:
        gyro_z_deg = 0

    # Integration
    angle_z += gyro_z_deg * dt

    # 3. Completion Detection
    if abs(angle_z) >= 160:
        print("Rotation detected!")

        # Parallel audio playback
        _thread.start_new_thread(music.play_mario_main_theme, (buzzer,))

        # Visual animation (5 loops)
        play_sui_animation()

        # API call + state update
        complete_and_switch_habit()

        # Display update
        display.display_active_habit(active_habits, active_habit_index)

        # Reset
        angle_z = 0.0
        utime.sleep_ms(1000)
        last_time = utime.ticks_ms()

    utime.sleep_ms(10)  # 100 Hz loop
```

### Przepływ Nawigacji Nawyków

```
Wciśnięcie Przycisku 1:
    → active_habit_index -= 1
    → if (index < 0): index = len(habits) - 1
    → Aktualizacja wyświetlacza
    → Reset kąta obrotu

Wciśnięcie Przycisku 2:
    → active_habit_index += 1
    → if (index >= len(habits)): index = 0
    → Aktualizacja wyświetlacza
    → Reset kąta obrotu

Wciśnięcie Obu Przycisków:
    → Wyświetlenie komunikatu "Loading Habits..."
    → GET /api/v1/habits/active
    → Parsowanie odpowiedzi JSON
    → Aktualizacja listy active_habits
    → Wyświetlenie pierwszego nawyku
    → Reset kąta obrotu
```
---

## Credits & Licenses

### Third-Party Libraries

**MPU-9250 Driver**
- Author: Mika Tuupola (@tuupola)
- Repository: [micropython-mpu9250](https://github.com/tuupola/micropython-mpu9250)
- License: MIT
- Version: 0.4.0

**SH1106 OLED Driver**
- Authors: Radomir Dopieralski, Robert Hammelrath, Tim Weber
- License: MIT

**Captive Portal**
- Inspiration: [amora-labs/micropython-captive-portal](https://github.com/amora-labs/micropython-captive-portal)

### Podsumowanie Specyfikacji
| Component | Model | Interface | GPIO/Address | Current Draw | Purpose |
| :--- | :--- | :--- | :--- | :--- | :--- |
| **MCU** | Raspberry Pi Pico WH | - | - | 80-100mA | Main controller |
| **Gyroscope** | MPU-9250 9DoF | I2C | SDA=0, SCL=1 | 3.5mA | Rotation detection |
| **Display** | SH1106 OLED 128x64 | SPI0 | CS=4, DC=5, RST=6 | 20mA | Visual output |
| **Button 1** | Membrane Switch | GPIO | Pin 17 (PULL_UP) | <1mA | Previous habit |
| **Button 2** | Membrane Switch | GPIO | Pin 16 (PULL_UP) | <1mA | Next habit |
| **Buzzer** | Grove Passive Buzzer | PWM | Pin 22 | 30mA (peak) | Audio feedback |
| **WiFi** | CYW43439 | Built-in | - | 80mA (active) | Network connectivity |
---
# Baza Danych 
> **Project:** Intelligent Habit Tracking Cube
> **Version:** 2.0
> **Last Updated:** December 7, 2025
> **Authors:** Paweł Klocek, Aleksy Dąda

## 1. Przegląd Techniczny

Warstwa danych systemu HabCube została zaprojektowana w oparciu o relacyjną bazę danych **PostgreSQL** oraz system cache'owania **Redis** dla zapewnienia wysokiej wydajności przy częstych zapytaniach z urządzeń IoT.

### Stos Technologiczny
* **Silnik Bazy Danych:** PostgreSQL 13+
* **Hosting:** Google Cloud SQL (Produkcja) / Docker (Lokalnie)
* **ORM (Object-Relational Mapping):** SQLAlchemy (Python)
* **Zarządzanie Migracjami:** Alembic (Flask-Migrate)
* **Cache:** Redis (Google Cloud Memorystore)

---

## Diagram ERD (Entity Relationship Diagram)

Poniższy diagram przedstawia relacje między głównymi encjami w systemie.
habcube

---

### Table: habits
| Column | Type | Description |
| :--- | :--- | :--- |
| `id` | INTEGER PRIMARY KEY | Unikalny identyfikator nawyku.|
| `name` | VARCHAR(100) | Nazwa nawyku (np. "Picie wody"). |
| `description` | TEXT | Opcjonalny opis lub motywacja. |
| `deadline_time` | TIME | Ostateczna godzina wykonania nawyku (np. 21:00). |
| `frequency` | ENUM | Częstotliwość: `daily`, `weekly`, `monthly`, `hourly`, etc. |
| `active` | BOOLEAN | Czy nawyk jest aktywny (Domyślnie: `TRUE`) |
| `created_at` | TIMESTAMP | Znacznik czasu utworzenia (Default: `CURRENT_TIMESTAMP`). |
| `color` | VARCHAR(10) | Kolor przypisany do nawyku (dla UI/LED). |
| `icon` | ENUM | Identyfikator ikony dla interfejsu użytkownika. |

### Table: habit_tasks
| Column | Type | Description |
| :--- | :--- | :--- |
| `id` | INTEGER PRIMARY KEY | Unikalny identyfikator zadania. |
| `habit_id` | INTEGER FK | Klucz obcy odnoszący się do `habits(id)`. |
| `date` | DATE | Data, na którą nawyk był zaplanowany/wykonany. |
| `completed` | BOOLEAN | Status ukończenia (Default: `FALSE`). |
| `completion_time` | TIMESTAMP | Dokładny znacznik czasu ukończenia (UTC). |

### Table: habit_statistics
| Column | Type | Description |
| :--- | :--- | :--- |
| `id` | INTEGER PRIMARY KEY | Unikalny identyfikator rekordu statystyk. |
| `habit_id` | INTEGER FK | Klucz obcy odnoszący się do `habits(id)`. |
| `total_completions` | INTEGER | Całkowita liczba udanych wykonań. |
| `current_streak` | INTEGER | Aktualna liczba wykonań z rzędu (passa). |
| `best_streak` | INTEGER | Najwyższa passa kiedykolwiek osiągnięta dla tego nawyku. |
| `success_rate` | FLOAT | Procent udanych wykonań w stosunku do okazji. |
| `last_completed` | DATE | Data ostatniego udanego wykonania. |
| `updated_at` | TIMESTAMP | Czas ostatniego przeliczenia statystyk. |

# HabCube - Dokumentacja Backendu
> **Project:** Intelligent Habit Tracking Cube
> **Version:** 2.0
> **Last Updated:** December 7, 2025
> **Authors:** Paweł Klocek, Aleksy Dąda

## Struktura Projektu

Projekt **HabCube** zorganizowany jest w strukturze monorepo, dzieląc kod na część backendową (API), frontendową (aplikacja mobilna) oraz dokumentację. Poniżej przedstawiono szczegółowe drzewo plików dla backendu.

### Drzewo Katalogów

```text
HabCube/
├── .venv/                   # Lokalne wirtualne środowisko Python
├── backend/                 # Główny katalog API (Flask)
│   ├── app/                 # Kod źródłowy aplikacji
│   │   ├── docs/            # Definicje Swagger/OpenAPI (pliki YAML)
│   │   │   ├── complete_habit.yml
│   │   │   ├── create_habit.yml
│   │   │   ├── finished_habits.yml
│   │   │   ├── get_habit.yml
│   │   │   ├── get_habits.yml
│   │   │   └── statistics.yml
│   │   ├── models/          # Warstwa danych (ORM & DTO)
│   │   │   ├── __init__.py
│   │   │   ├── dto.py       # Obiekty transferu danych (walidacja wejścia)
│   │   │   ├── enums.py     # Typy wyliczeniowe (np. FrequencyType, HabitIcon)
│   │   │   └── habit.py     # Modele bazy danych (Habit, HabitTask, Statistics)
│   │   ├── routes/          # Kontrolery / Endpointy API
│   │   │   ├── __init__.py
│   │   │   └── habits.py    # Logika biznesowa zarządzania nawykami
│   │   ├── __init__.py      # Inicjalizacja aplikacji (Factory Pattern)
│   │   ├── cli.py           # Niestandardowe komendy CLI
│   │   ├── config.py        # Konfiguracja zmiennych środowiskowych i bazy
│   │   └── swagger.py       # Konfiguracja generatora dokumentacji API
│   ├── logs/                # Katalog na pliki logów serwera
│   ├── migrations/          # Skrypty migracyjne bazy danych (Alembic)
│   ├── tests/               # Testy jednostkowe i integracyjne
│   ├── .dockerignore        # Pliki ignorowane przez Docker context
│   ├── .pylintrc            # Konfiguracja lintera kodu (Pylint)
│   ├── Dockerfile           # Instrukcja budowania obrazu kontenera
│   ├── requirements.txt     # Lista zależności bibliotecznych Python
│   ├── setup.cfg            # Konfiguracja narzędzi (flake8, mypy)
│   └── wsgi.py              # Punkt wejścia dla serwera WSGI (Gunicorn)
├── docs/                    # Ogólna dokumentacja projektowa i schematy
└── frontend/                # Kod źródłowy aplikacji mobilnej (React Native)
```
## Logika Biznesowa i Endpointy
Moduł odpowiedzialny za zarządzanie nawykami, ich harmonogramem, śledzeniem postępów i statystykami.

## Spis Endpointów

| Metoda | Endpoint | Opis |
| :--- | :--- | :--- |
| `GET` | `/habits` | Pobiera listę wszystkich nawyków. |
| `GET` | `/habits/active` | Pobiera nawyki gotowe do wykonania (zgodnie z harmonogramem). |
| `GET` | `/finished-habits` | Pobiera zakończone nawyki wraz ze statusem sukcesu. |
| `GET` | `/statistics` | Pobiera ogólne statystyki użytkownika. |
| `GET` | `/habits/<id>` | Pobiera szczegóły pojedynczego nawyku. |
| `POST` | `/habits` | Tworzy nowy nawyk. |
| `POST` | `/habits/<id>/complete` | Oznacza nawyk jako wykonany. |

---

## Szczegółowy Opis

### 1. Pobierz wszystkie nawyki
Zwraca listę wszystkich nawyków zapisanych w bazie danych.

- **URL:** `/habits`
- **Metoda:** `GET`
- **Odpowiedź sukcesu (200 OK):**
  ```json
  {
    "habits": [
      {
        "id": 1,
        "name": "Bieganie",
        "description": "30 min rano",
        "active": true,
        ...
      }
    ]
  }
    ```
#### Kod Python
```python
@habits_bp.route("/habits", methods=["GET"])
@swag_from(os.path.join(DOCS_DIR, "get_habits.yml"))
def get_habits():
    try:
        habits = Habit.query.all()
        return jsonify({"habits": [habit.to_dict() for habit in habits]}), 200

    except Exception as e:
        return jsonify({"error": f"Failed to fetch habits: {str(e)}"}), 500
```

### 2. Pobierz aktywne nawyki (Do wykonania)
Zwraca listę nawyków, które są aktywne i gotowe do wykonania w danym momencie. Dostępność zależy od częstotliwości nawyku i czasu ostatniego wykonania.

- **URL:** /habits/active

- **Metoda:** : GET

- **Logika dostępności**:
    - Nigdy niewykonane: Zawsze dostępne.
    - Co 30 min / 1h / 3h / 6h: Dostępne po upływie określonego czasu od ostatniego wykonania.
    - Dziennie (Daily): Dostępne, jeśli ostatnie wykonanie było przed dniem dzisiejszym.
    - Tygodniowo (Weekly): Dostępne po 7 dniach.
    - Miesięcznie (Monthly): Dostępne po 30 dniach.

#### Kod Python
```python
@habits_bp.route("/habits/active", methods=["GET"])
def get_active_habits():
    try:
        now = datetime.utcnow()
        today = date.today()

        # Get all active habits
        active_habits = Habit.query.filter_by(active=True).all()

        ready_habits = []
        for habit in active_habits:
            # Get last completion
            last_task = HabitTask.query.filter_by(
                habit_id=habit.id,
                completed=True
            ).order_by(HabitTask.completion_time.desc()).first()

            is_ready = False

            if not last_task:
                # Never completed, always ready
                is_ready = True
            else:
                last_completion = last_task.completion_time
                time_diff = now - last_completion

                # Check based on frequency
                if habit.frequency == FrequencyType.EVERY_30_MIN.value:
                    is_ready = time_diff.total_seconds() >= 30 * 60
                elif habit.frequency == FrequencyType.HOURLY.value:
                    is_ready = time_diff.total_seconds() >= 60 * 60
                elif habit.frequency == FrequencyType.EVERY_3_HOURS.value:
                    is_ready = time_diff.total_seconds() >= 3 * 60 * 60
                elif habit.frequency == FrequencyType.EVERY_6_HOURS.value:
                    is_ready = time_diff.total_seconds() >= 6 * 60 * 60
                elif habit.frequency == FrequencyType.DAILY.value:
                    # Ready if last completion was before today
                    is_ready = last_task.date < today
                elif habit.frequency == FrequencyType.WEEKLY.value:
                    # Ready if last completion was 7+ days ago
                    is_ready = (today - last_task.date).days >= 7
                elif habit.frequency == FrequencyType.MONTHLY.value:
                    # Ready if last completion was 30+ days ago
                    is_ready = (today - last_task.date).days >= 30

            if is_ready:
                ready_habits.append(habit.to_dict())

        return jsonify({"habits": ready_habits}), 200

    except Exception as e:
        return jsonify({"error": f"Failed to fetch active habits: {str(e)}"}), 500
```
### 3. Pobierz zakończone nawyki
Zwraca listę nawyków oznaczonych jako nieaktywne (`active=False`). Oblicza, czy nawyk zakończył się sukcesem.

- **URL:** /finished-habits

- **Metoda:** GET

- **Kryterium sukcesu:** Pole success_status jest true, jeśli najlepsza seria (best_streak) wynosiła 21 dni lub więcej.

- **Przykładowa odpowiedź:**
```json
{
  "habits": [
    {
      "id": 10,
      "name": "Joga",
      "best_streak": 25,
      "success_status": true,
      "finish_date": "Tue, 10 Oct 2023 00:00:00 GMT"
    }
  ]
}
```
#### Kod Python
```python
@habits_bp.route("/finished-habits", methods=["GET"])
@swag_from(os.path.join(DOCS_DIR, "finished_habits.yml"))
def get_finished_habits():
    try:
        habits = Habit.query.filter_by(active=False).all()
        finished_habits = []
        for habit in habits:
            finished_habit = {}
            habit_dict = habit.to_dict()
            finished_habit["id"] = habit_dict["id"]
            finished_habit["name"] = habit_dict["name"]
            finished_habit["description"] = habit_dict["description"]
            finished_habit["icon"] = habit_dict["icon"]

            if habit.statistics:
                stats_data = habit.statistics.to_dict()
                best_streak = stats_data.get("best_streak", 0)
                finished_habit["best_streak"] = best_streak
                if int(best_streak) >= 21:
                    finished_habit["success_status"] = True
                else:
                    finished_habit["success_status"] = False
                finished_habit["finish_date"] = stats_data["last_completed"]
            else:
                finished_habit["best_streak"] = 0
                finished_habit["success_status"] = False
                finished_habit["finish_date"] = ''

            finished_habits.append(finished_habit)

        return jsonify({"habits": finished_habits}), 200

    except Exception as e:
        print(f"Error: {e}")
        return jsonify({"error": f"Failed to fetch habits: {str(e)}"}), 500
```

### 4. Statystyki ogólne
Zwraca zagregowane dane statystyczne dla wszystkich nawyków.

- **URL:** `/statistics`

- **Metoda:** `GET`

- **Zwracane dane:**
    - `total_habits`: Łączna liczba nawyków.
    - `active_habits_count`: Liczba trwających nawyków.
    - `completed_habits_count`: Liczba zakończonych nawyków.
    - `longest_streak`: Najdłuższa seria (streak) w historii użytkownika.
    - `average_completion_rate`: Średni wskaźnik sukcesu (zaokrąglony do 2 miejsc po przecinku).
#### Kod Python:
```python
@habits_bp.route("/statistics", methods=["GET"])
def get_habits_statistics():
    try:
        total_habits = db.session.query(func.count(Habit.id)).scalar()

        active_habits_count = db.session.query(Habit).filter_by(active=True).count()
        inactive_habits_count = total_habits - active_habits_count

        longest_streak = db.session.query(func.max(HabitStatistics.best_streak)).scalar()

        if longest_streak is None:
            longest_streak = 0

        average_completion_rate = db.session.query(
            func.avg(HabitStatistics.success_rate)
        ).scalar()

        if average_completion_rate is None:
            average_completion_rate = 0.0
        else:
            average_completion_rate = round(average_completion_rate, 2)

        response_data = {
            "total_habits": total_habits,
            "active_habits_count": active_habits_count,
            "completed_habits_count": inactive_habits_count,
            "longest_streak": longest_streak,
            "average_completion_rate": average_completion_rate
        }

        return jsonify(response_data), 200

    except Exception as e:
        print(f"Error fetching global statistics: {e}")
        return jsonify({"error": f"Failed to fetch statistics: {str(e)}"}), 500
```

### 5. Pobierz szczegóły nawyku
Pobiera pełne dane pojedynczego nawyku, w tym jego indywidualne statystyki.

- **URL:** `/habits/<int:habit_id>`

- **Metoda:** `GET`

- **Błędy:** `404` jeśli nawyk nie istnieje.

#### Kod Python
```python
@habits_bp.route("/habits/<int:habit_id>", methods=["GET"])
@swag_from(os.path.join(DOCS_DIR, "get_habit.yml"))
def get_habit(habit_id):
    try:
        habit = db.session.get(Habit, habit_id)

        if not habit:
            return jsonify({"error": "Habit not found"}), 404

        response_data = habit.to_dict()

        # Include statistics if available
        if habit.statistics:
            response_data["statistics"] = habit.statistics.to_dict()

        return jsonify(response_data), 200

    except Exception as e:
        return jsonify({"error": f"Failed to fetch habit: {str(e)}"}), 500

```
### 6. Utwórz nowy nawyk
Tworzy nowy nawyk i inicjalizuje dla niego statystyki.

- **URL:** `/habits`

- **Metoda:** `POST`

- **Body** (JSON):

    - `name` (string, wymagane)
    - `description` (string, opcjonalne)
    - `deadline_time` (string "HH:MM", opcjonalne)
    - `frequency` (enum, domyślnie "DAILY")
    - `icon` (enum, domyślnie "STAR")
    - `type` (enum, domyślnie "WATER")

#### Walidacja:
Sprawdza poprawność formatu godziny.
Weryfikuje czy `frequency`, `icon` i `type` są zgodne z dozwolonymi wartościami (Enum).

#### Kod Python
```python
@habits_bp.route("/habits", methods=["POST"])
@swag_from(os.path.join(DOCS_DIR, "create_habit.yml"))
def create_habit():
    try:
        data = request.get_json()

        if not data:
            return jsonify({"error": "No data provided"}), 400

        # Parse deadline_time if provided
        deadline_time = None
        if "deadline_time" in data and data["deadline_time"]:
            try:
                deadline_time = datetime.strptime(data["deadline_time"], "%H:%M").time()
            except ValueError:
                return (
                    jsonify({"error": "Invalid deadline_time format. Use HH:MM"}),
                    400,
                )

        # Validate frequency
        frequency = data.get("frequency", FrequencyType.DAILY.value)
        if not FrequencyType.is_valid(frequency):
            return (
                jsonify(
                    {
                        "error": f"Invalid frequency. Must be one of: {', '.join(FrequencyType.choices())}"
                    }
                ),
                400,
            )

        # Validate icon
        icon = data.get("icon", HabitIcon.STAR.value)
        if icon and not HabitIcon.is_valid(icon):
            return (
                jsonify({"error": "Invalid icon"}),
                400,
            )

        # Validate type
        from app.models.enums import HabitType
        habit_type = data.get("type", HabitType.WATER.value)
        if habit_type and not HabitType.is_valid(habit_type):
            return (
                jsonify(
                    {
                        "error": f"Invalid type. Must be one of: {', '.join(HabitType.choices())}"
                    }
                ),
                400,
            )

        # Create DTO and validate
        dto = CreateHabitDTO(
            name=data.get("name"),
            description=data.get("description"),
            deadline_time=deadline_time,
            frequency=frequency,
            icon=icon,
        )

        is_valid, error_message = dto.validate()
        if not is_valid:
            return jsonify({"error": error_message}), 400

        # Create new habit
        habit = Habit(
            name=dto.name,
            description=dto.description,
            deadline_time=dto.deadline_time,
            frequency=dto.frequency,
            icon=dto.icon,
            type=habit_type,
            active=True,
        )

        db.session.add(habit)
        db.session.flush()

        # Create initial statistics record
        statistics = HabitStatistics(habit_id=habit.id)
        db.session.add(statistics)

        db.session.commit()

        return (
            jsonify(
                {"message": "Habit created successfully", "habit": habit.to_dict()}
            ),
            201,
        )

    except Exception as e:
        db.session.rollback()
        return jsonify({"error": f"Failed to create habit: {str(e)}"}), 500

```

### 7. Wykonaj nawyk
Oznacza nawyk jako wykonany ("odkliknięty") w dniu dzisiejszym.

- **URL:** `/habits/<int:habit_id>/complete`

- **Metoda:** `POST`

- **Logika biznesowa:**

    - Blokuje podwójne wykonanie tego samego dnia (chyba że częstotliwość na to pozwala - uwaga: w kodzie jest twarda blokada `Habit already completed today` dla wpisów z tą samą datą).

    - **Aktualizacja serii (Streak):**

        - Pierwsze wykonanie: Streak = 1.

        - Wykonanie dzień po dniu: Streak + 1.

        - Przerwa w wykonaniu (>1 dzień): Reset Streak do 1.

    - Aktualizuje `best_streak` jeśli obecna seria jest rekordowa.

#### Kod Python
```python
@habits_bp.route("/habits/<int:habit_id>/complete", methods=["POST"])
@swag_from(os.path.join(DOCS_DIR, "complete_habit.yml"))
def complete_habit(habit_id):
    try:
        habit = db.session.get(Habit, habit_id)

        if not habit:
            return jsonify({"error": "Habit not found"}), 404

        completion_date = date.today()

        # Check if already completed today
        existing_task = HabitTask.query.filter_by(
            habit_id=habit_id, date=completion_date
        ).first()

        if existing_task and existing_task.completed:
            return jsonify({"error": "Habit already completed today"}), 400

        # Create completion task
        task = HabitTask(
            habit_id=habit_id,
            date=completion_date,
            completed=True,
            completion_time=datetime.utcnow(),
        )
        db.session.add(task)

        # Update statistics
        statistics = habit.statistics
        if not statistics:
            statistics = HabitStatistics(habit_id=habit_id)
            db.session.add(statistics)

        statistics.total_completions += 1
        statistics.last_completed = completion_date
        statistics.updated_at = datetime.utcnow()

        # Update streak
        if statistics.total_completions == 1:
            statistics.current_streak = 1
        else:
            # Check previous completion
            previous_task = (
                HabitTask.query.filter_by(habit_id=habit_id, completed=True)
                .filter(HabitTask.date < completion_date)
                .order_by(HabitTask.date.desc())
                .first()
            )
            if previous_task:
                days_diff = (completion_date - previous_task.date).days
                if days_diff == 1:
                    statistics.current_streak += 1
                else:
                    statistics.current_streak = 1
            else:
                statistics.current_streak = 1

        # Update best streak
        if statistics.current_streak > statistics.best_streak:
            statistics.best_streak = statistics.current_streak

        db.session.commit()

        return (
            jsonify(
                {
                    "message": "Habit completed successfully",
                    "task": task.to_dict(),
                    "statistics": statistics.to_dict(),
                }
            ),
            200,
        )

    except Exception as e:
        db.session.rollback()
        return jsonify({"error": f"Failed to complete habit: {str(e)}"}), 500
```

### 6. Dokumentacja API (Swagger)
Aplikacja wykorzystuje bibliotekę Flasgger. Definicje endpointów są oddzielone od kodu i znajdują się w katalogu `app/docs/*.yml`.

Po uruchomieniu serwera, pełna interaktywna dokumentacja dostępna jest pod adresem:

`http://localhost:5000/api/docs/`

#### Przykładowa konfiguracja pliku `yml`:
```yml
tags:
  - Habits
summary: Get a single habit by ID
description: Returns habit details including statistics if available
parameters:
  - name: habit_id
    in: path
    type: integer
    required: true
    description: ID of the habit
responses:
  200:
    description: Habit details with statistics
    examples:
      success:
        id: 1
        name: "Drink water"
        description: "Drink 8 glasses of water daily"
        deadline_time: "21:00:00"
        frequency: "daily"
        active: true
        created_at: "2025-10-15T10:30:00"
        statistics:
          id: 1
          habit_id: 1
          total_completions: 15
          current_streak: 5
          best_streak: 10
          success_rate: 85.5
          last_completed: "2025-10-14"
          updated_at: "2025-10-14T22:15:00"
  404:
    description: Habit not found
    examples:
      error:
        error: "Habit not found"
  500:
    description: Server error

```

## Wdrożenie (Google Cloud Run)

Poniższy plik konfiguracyjny (`cloudbuild.yaml`) definiuje kompletny pipeline wdrożeniowy dla backendu aplikacji. Proces ten realizuje podejście **Infrastructure as Code** i jest uruchamiany automatycznie przez Google Cloud Build.

## Proces

1.  **Build (Budowanie Obrazu):**
    System tworzy obraz Docker na podstawie kodu z katalogu `./backend`, oznaczając go odpowiednim tagiem.

2.  **Push (Wypchnięcie do Rejestru):**
    Gotowy obraz jest przesyłany do **Google Artifact Registry**, skąd będzie dostępny dla usług chmurowych.

3.  **Deploy (Wstępne Wdrożenie na Cloud Run):**
    Nowa wersja aplikacji jest instalowana na serwerze, ale z flagą `--no-traffic` (nie jest jeszcze publicznie dostępna).
    * **Integracja z bazą:** Usługa jest łączona z instancją Cloud SQL (`--add-cloudsql-instances`).
    * **Bezpieczeństwo:** Hasła i klucze (DB_PASSWORD, SECRET_KEY) są bezpiecznie wstrzykiwane z **Secret Manager**.

4.  **Database Migration (Automatyczna Migracja Bazy):**
    Kluczowy moment procesu. System tworzy i uruchamia jednorazowe zadanie (**Cloud Run Job**) o nazwie `backend-migrate`.
    * Zadanie wykonuje komendę `flask db upgrade`.
    * Dzięki temu struktura bazy danych jest aktualizowana do nowej wersji kodu *zanim* użytkownicy zaczną z niej korzystać.

5.  **Traffic Switch (Przełączenie Ruchu):**
    Dopiero po pomyślnej migracji bazy, 100% ruchu użytkowników jest przekierowywane na nową, przetestowaną wersję aplikacji.

---

## Pełna Konfiguracja (`cloudbuild.yaml`)

```yaml
steps:
  # 1. Build Docker image
  - name: "gcr.io/cloud-builders/docker"
    args: ["build", "-t", "${_IMAGE_TAG}", "./backend"]

  # 2. Push Docker image to Artifact Registry
  - name: "gcr.io/cloud-builders/docker"
    args: ["push", "${_IMAGE_TAG}"]

  # 3. Deploy to Cloud Run (bez ruchu publicznego)
  - name: "gcr.io/[google.com/cloudsdktool/cloud-sdk](https://google.com/cloudsdktool/cloud-sdk)"
    entrypoint: "bash"
    args:
      - "-c"
      - |
        gcloud run deploy backend \
          --image "${_IMAGE_TAG}" \
          --region "${_REGION}" \
          --service-account "${_SERVICE_ACCOUNT}" \
          --memory=4Gi \
          --cpu=2 \
          --timeout=300 \
          --add-cloudsql-instances "${_CLOUD_SQL_CONNECTION_NAME}" \
          --set-env-vars "FLASK_ENV=production,DB_HOST=/cloudsql/${_CLOUD_SQL_CONNECTION_NAME},DB_PORT=5432,DB_USER=${_DB_USER},DB_NAME=${_DB_NAME}" \
          --update-secrets "DB_PASSWORD=db-password:latest,SECRET_KEY=flask-key:latest,JWT_SECRET_KEY=jwt-key:latest" \
          --no-traffic

  # 4. Database Migration (Flask DB Upgrade)
  - name: "gcr.io/[google.com/cloudsdktool/cloud-sdk](https://google.com/cloudsdktool/cloud-sdk)"
    entrypoint: "bash"
    args:
      - "-c"
      - |
        set -e
        gcloud run jobs delete backend-migrate --region "${_REGION}" --quiet || true
        gcloud run jobs create backend-migrate \
          --image "${_IMAGE_TAG}" \
          --region "${_REGION}" \
          --service-account "${_SERVICE_ACCOUNT}" \
          --set-cloudsql-instances "${_CLOUD_SQL_CONNECTION_NAME}" \
          --set-env-vars "FLASK_ENV=production,FLASK_APP=wsgi:app,DB_HOST=/cloudsql/${_CLOUD_SQL_CONNECTION_NAME},DB_PORT=5432,DB_USER=${_DB_USER},DB_NAME=${_DB_NAME}" \
          --update-secrets "DB_PASSWORD=db-password:latest,SECRET_KEY=flask-key:latest,JWT_SECRET_KEY=jwt-key:latest" \
          --command "flask" --args "db","upgrade" \
          --task-timeout 10m
        gcloud run jobs execute backend-migrate --region "${_REGION}" --wait
        
  # 5. Switch traffic to new revision (Upublicznienie)
  - name: "gcr.io/[google.com/cloudsdktool/cloud-sdk](https://google.com/cloudsdktool/cloud-sdk)"
    entrypoint: "bash"
    args:
      - "-c"
      - |
        gcloud run services update-traffic backend \
          --region "${_REGION}" \
          --to-latest

substitutions:
  _REGION: "europe-west1"
  _IMAGE_TAG: "europe-west1-docker.pkg.dev/project-5291a779-124c-4d04-8a5/cloud-run-source-deploy/habcube-backend:latest"
  _SERVICE_ACCOUNT: "1089871134307-compute@developer.gserviceaccount.com"
  _CLOUD_SQL_CONNECTION_NAME: "project-5291a779-124c-4d04-8a5:europe-west1:habcube"
  _DB_USER: "postgres"
  _DB_NAME: "postgres"

options:
  logging: CLOUD_LOGGING_ONLY
```
## Uruchomienie Deweloperskie

### Konfigutacja środowiska

**Ważne:**
Najpierw uruchom skrypt instalacyjny, który automatycznie doda `export CURRENT_UID` do `~/.bashrc` (pozwoli to uniknąć późniejszych problemów z uprawnieniami do plików i folderów):

```bash
./setup-env.sh
source ~/.bashrc
```

### Pierwsze uruchomienie
```bash
# 1. Zbudowanie obrazu docker
docker-compose up -d --build

# 2. Sprawdzenie statusu kontenera
docker-compose ps

# 3. Logi
docker-compose logs -f backend

# 4. Sprawdzenie statusu `health` aplikacji
curl http://localhost:5000/health
```
### Uruchomienie aplikacji
```bash
# Start
docker-compose up -d

# Stop
docker-compose down
```
### Makefile (Rekomendowane)
Plik Makefile automatycznie eksportuje CURRENT_UID:
```bash
make init # Pierwsze uruchomienie / Inicjalizacja
make up # Uruchom usługi
make down # Zatrzymaj usługi
make logs # Wyświetl logi
make test # Uruchom testy
make help # Wyświetl wszystkie polecenia
```
### Dostęp do serwisu
Backend: http://localhost:5000

Adminer (DB UI): http://localhost:8080

PostgreSQL: localhost:5432

Redis: localhost:6379
### Podstawowe komendy
```bash
# Basic Docker
docker-compose up -d
docker-compose down
docker-compose logs -f
docker-compose ps

# Rebuild
docker-compose build
docker-compose up -d --build

# Shell Access
docker-compose exec backend bash

# Tests and Code Quality
docker-compose exec backend pytest
docker-compose exec backend pytest --cov=app
docker-compose exec backend flake8 app/
docker-compose exec backend black app/
docker-compose exec backend pylint app/
docker-compose exec backend mypy app/

# Database Management
docker-compose exec postgres psql -U habcube_user -d habcube
docker-compose exec backend flask db migrate -m "description"
docker-compose exec backend flask db upgrade

# Makefile
make help
```

# Dokumentacja Aplikacji Mobilnej HabCube
> **Project:** Intelligent Habit Tracking Cube
> **Version:** 2.0
> **Last Updated:** December 7, 2025
> **Author:** Szymon Domagała

## 1. Przegląd
Aplikacja mobilna HabCube to wieloplatformowe rozwiązanie zbudowane w oparciu o **React Native (Expo)** oraz **TypeScript**. Pełni ona rolę głównego interfejsu użytkownika do konfiguracji nawyków, śledzenia postępów oraz wizualizacji statystyk pochodzących z urządzenia IoT Cube.

## 2. Stack Technologiczny

* **Framework:** React Native (Expo) – umożliwia szybki rozwój na Androida, iOS oraz Web.
* **Język:** TypeScript (5.9.2) – zapewnia statyczne typowanie kodu.
* **Narzędzia Buildowania:** Expo CLI / EAS (Expo Application Services).
* **Nawigacja:** React Navigation (Native Stack).
* **Klient HTTP:** Axios.
* **Zarządzanie Stanem:** React Hooks (`useState`, `useEffect`, Custom Hooks).
* **Kluczowe Biblioteki:**
    * `@react-native-picker/picker` – natywne listy wyboru.
    * `react-native-toast-message` – obsługa powiadomień i alertów.
    * `react-native-vector-icons` – zestaw ikon (Ionicons).
    * `@react-native-community/datetimepicker` – wybór daty i czasu.

## 3. Struktura Projektu

Projekt podąża za strukturą opartą na funkcjonalnościach i komponentach (`Feature-based`):

```text
src/
├── api/                  # Warstwa komunikacji z API
│   ├── client.ts         # Konfiguracja instancji Axios
│   ├── endpoints.ts      # Stałe z adresami URL
│   └── habits.api.ts     # Funkcje serwisowe (GET, POST)
├── assets/
│   ├── data/             # Dane statyczne (np. lista dostępnych ikon)
│   └── ...               # Obrazy i zasoby graficzne
├── components/           # Komponenty UI i Ekrany
│   ├── AddHabit/         # Ekran tworzenia nawyku (logika formularza)
│   ├── AppLogo/          # Reużywalny komponent logo
│   ├── BottomNavbar/     # Dolny pasek nawigacyjny
│   ├── FinishedHabits/   # Ekran historii i archiwum
│   ├── HabitsStats/      # Ekran statystyk globalnych
│   ├── MainPage/         # Dashboard (Aktywne nawyki)
│   └── WelcomeScreen.tsx # Ekran powitalny
├── constants/
│   └── config.ts         # Konfiguracja środowiskowa (URL backendu)
├── hooks/                # Logika biznesowa (Custom Hooks)
│   ├── useCreateHabit.ts
│   ├── useHabits.ts
│   └── ...
└── types/
    └── habit.types.ts    # Interfejsy i typy TypeScript (DTO)
```

### 4. Architektura i Przepływ Danych
Aplikacja wykorzystuje wzorzec Service-Hook-Component w celu separacji odpowiedzialności:

- **Warstwa API (src/api):** Obsługuje bezpośrednią komunikację HTTP przez Axios. Definiuje endpointy i surowe funkcje pobierania danych.

- **Warstwa Hooków (src/hooks):** Hermetyzuje logikę biznesową. Wywołuje warstwę API i wystawia proste zmienne (data, loading, error) dla UI.

- **Warstwa UI (src/components):** Komponenty prezentacyjne, które konsumują Hooki do wyświetlania danych.

**Konfiguracja** (`src/constants/config.ts`)
Plik konfiguracyjny pozwala na łatwe dostosowanie adresu backendu. Aplikacja może wykrywać środowisko, ale zaleca się ręczne ustawienie adresu IP w przypadku testów na fizycznym urządzeniu (jeśli backend nie jest w chmurze).

### 5. Szczegółowy Opis Komponentów

#### Ekran Dodawania Nowego Nawyku (`src/components/AddHabit/index.tsx`)
Jest to kluczowy moduł odpowiedzialny za logikę tworzenia nowych instancji nawyków.

**Funkcjonalności formularza:** Użytkownik wprowadza następujące dane:
- Nazwa (np. `"Picie wody"`)
- Opis (szczegóły celu)
- Ikona (wybór z wizualnej listy)
- Typ (np. `"Zdrowie"`, `"Sport"`)
- Częstotliwość (np. `"Codziennie"`, `"Tygodniowo"` - obsługa przez `Picker`)
- Data startu (obsługa przez `DateTimePicker`)

Logika Procesu (`handleSubmit`): Funkcja handleSubmit jest sercem tego ekranu i realizuje następujący przepływ:
- Zbieranie Danych: Agreguje dane z pól formularza do obiektu habitData.
- Walidacja: Sprawdza kompletność wymaganych pól.
- Komunikacja: Wywołuje hook addHabit (POST request).

Feedback:
- **Sukces:** Wyświetla powiadomienie Toast ("Habit created") i przekierowuje na MainPage.
- **Błąd:** Wyświetla powiadomienie Toast z treścią błędu, pozwalając na ponowną próbę.

Ekran Dodawania Nawyku (`src/components/AddHabit/index.tsx`)
Interaktywny formularz umożliwiający użytkownikowi zdefiniowanie nowego nawyku. Komponent obsługuje wprowadzanie danych tekstowych, wybór parametrów z list oraz komunikację z API.

#### Kluczowe funkcjonalności w kodzie:

1. Zarządzanie Stanem Formularza: Komponent wykorzystuje useState do przechowywania wartości wprowadzanych przez użytkownika (nazwa, opis, typ, częstotliwość, data startu).

2. Obsługa Złożonych Kontrolek UI:
    - **Wybór Ikony**: Renderowanie siatki ikon (AVAILABLE_ICONS) z wizualnym podświetleniem wybranego elementu.
    - **Pickery**: Wykorzystanie @react-native-picker/picker do wyboru typu aktywności i częstotliwości.
    - **Data:** Integracja z natywnym DateTimePicker.

3. Logika Wysyłania (`handleSubmit`): Funkcja buduje obiekt DTO, wysyła go do backendu, a następnie obsługuje informację zwrotną (Toast) i nawigację.
```tsx
// Przygotowanie danych i wysyłka do API
const handleSubmit = async () => {
  // Konstrukcja obiektu zgodnego z DTO backendu
  const habitData: ICreateHabitDTO = {
    name: habitName,
    description: habitDescription,
    icon: habitIcon,          // Ikona wybrana z siatki
    frequency: habitFrequency,// np. 'daily', 'weekly'
    created_at: habitStartDate.toISOString(),
    type: habitIconType,
  };

  try {
    // Wywołanie custom hooka obsługującego żądanie POST
    const response = await addHabit(habitData);

    if (response) {
      // Pozytywny feedback i przekierowanie po opóźnieniu
      Toast.show({
        type: 'success',
        text1: 'Habit added successfully!',
        position: 'bottom',
        visibilityTime: 2000,
      });
      setTimeout(() => {
        navigation.navigate("MainPage");
      }, 2500);
    }
  } catch (err) {
    // Obsługa błędów
    Toast.show({
      type: 'error',
      text1: 'Failed to add habit.',
      position: 'bottom',
    });
  }
};  
```
#### Dashboard Główny (`src/components/MainPage/index.tsx`)
Centrum dowodzenia użytkownika.
* **Funkcje:** Wyświetla listę aktywnych nawyków pobranych z API.
* **Interakcja:** Kliknięcie w nawyk oznacza go jako wykonany (wysyła żądanie `COMPLETE` do backendu).
* **Wizualizacja:** Prezentuje pasek postępu (Progress Bar) dążący do celu 21 dni oraz licznik obecnej serii (Streak).

**Dashboard Główny** (src/components/MainPage/index.tsx)
Centrum dowodzenia użytkownika. Odpowiada za wyświetlanie listy aktywnych nawyków, ich statusu oraz postępów.

### Kluczowe funkcjonalności w kodzie:

1. Automatyczne odświeżanie danych: Wykorzystanie useFocusEffect zapewnia, że lista nawyków jest zawsze aktualna po powrocie z innych ekranów (np. po dodaniu nowego nawyku).
```tsx
const { fetchHabits, habits } = useHabits();

useFocusEffect(
  React.useCallback(() => {
    fetchHabits(); // Pobranie danych przy każdym wejściu na ekran
  }, [])
);
```

2. **Renderowanie Karty Nawyku i Paska Postępu:** Dynamiczne obliczanie szerokości paska postępu (na podstawie celu 21 dni) oraz wyświetlanie aktualnej serii (Streak).
```tsx
const renderHabitItem = (habit: IHabit) => (
  <View key={habit.id} style={styles.habitCard}>
    {/* ... Nagłówek i Ikona ... */}

    <View style={styles.habitInfo}>
      <Text style={styles.habitName}>{habit.name}</Text>
      <Text style={styles.habitFrequency}>
        {/* Wyświetlanie częstotliwości i serii */}
        {habit.frequency} • Streak: {habit.statistics?.current_streak} days
      </Text>
    </View>

    {/* Przycisk wykonania (zmiana stylu jeśli zrobione dzisiaj) */}
    <TouchableOpacity
      style={[
        styles.checkButton,
        // Sprawdzenie czy data ostatniego wykonania to "dzisiaj"
        habit.statistics?.last_completed === new Date().toISOString().split('T')[0] 
          && styles.checkButtonCompleted,
      ]}
      onPress={() => handleCompleteHabit(habit.id)}
    >
       {/* ... Ikona checkmark ... */}
    </TouchableOpacity>

    {/* Pasek Postępu (Progress Bar) */}
    <View style={styles.progressContainer}>
      <View style={styles.progressBarBackground}>
        <View
          style={[
            styles.progressBarFill,
            // Obliczanie % ukończenia celu 21 dni
            { width: `${(habit.statistics?.total_completions / 21) * 100}%` },
          ]}
        />
      </View>
      <Text style={styles.progressText}>
        {habit.statistics?.total_completions} / 21 days
      </Text>
    </View>
  </View>
);
```

#### Statystyki (`src/components/HabitsStats/index.tsx`)
Ekran analityczny.
* **Dane:** Agreguje dane globalne: łączna liczba nawyków, najdłuższa seria, średnia skuteczność.
* **Odświeżanie:** Wykorzystuje `useFocusEffect` do odświeżania danych przy każdym wejściu na ekran.

Ekran analityczny, który agreguje i wizualizuje globalne postępy użytkownika w aplikacji.

#### Kluczowe funkcjonalności w kodzie:

1. Pobieranie Danych Agregowanych: Komponent korzysta z dedykowanego hooka `useStatsHabits`, który komunikuje się z endpointem `/statistics` backendu. Zwraca on gotowy obiekt ze statystykami, co oddziela warstwę prezentacji od logiki pobierania danych.
```tsx
// Pobranie danych statystycznych z API
const { stats, loading, error } = useStatsHabits();
```
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

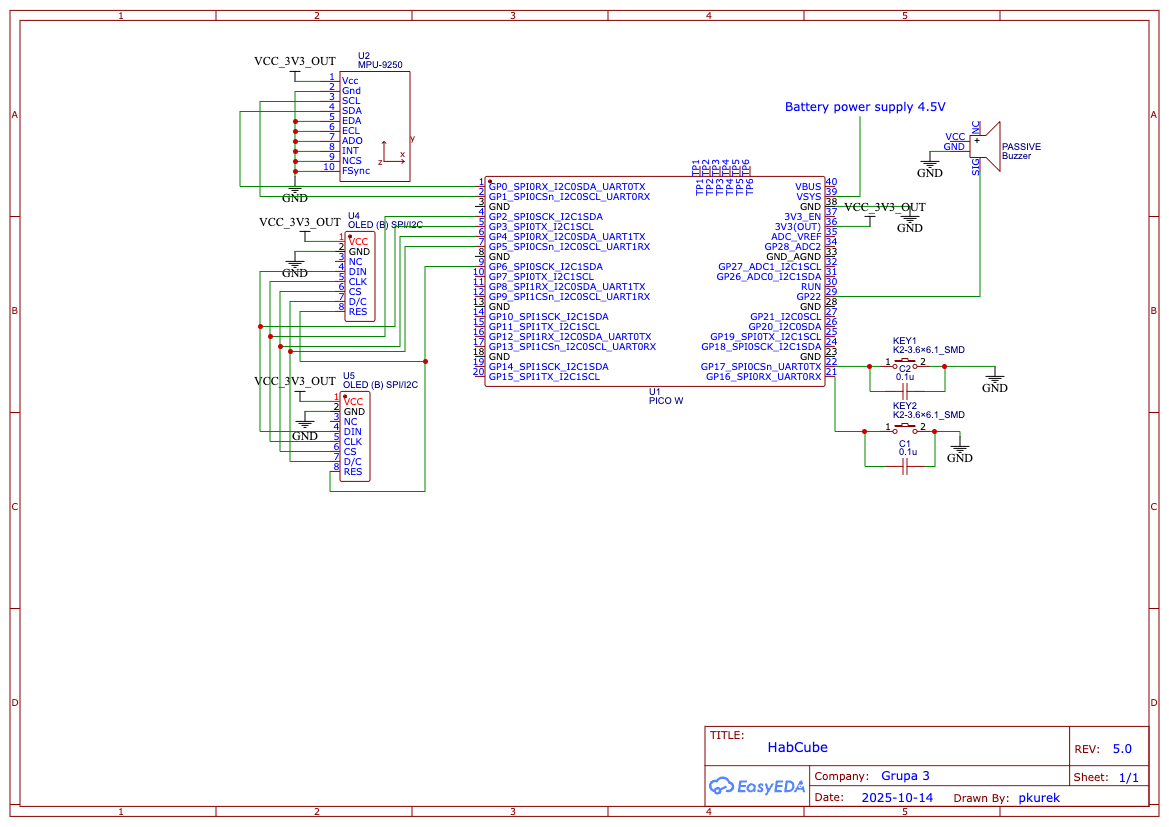
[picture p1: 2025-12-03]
docs/schema/Schematic_IOT2025_2025-11-29.png

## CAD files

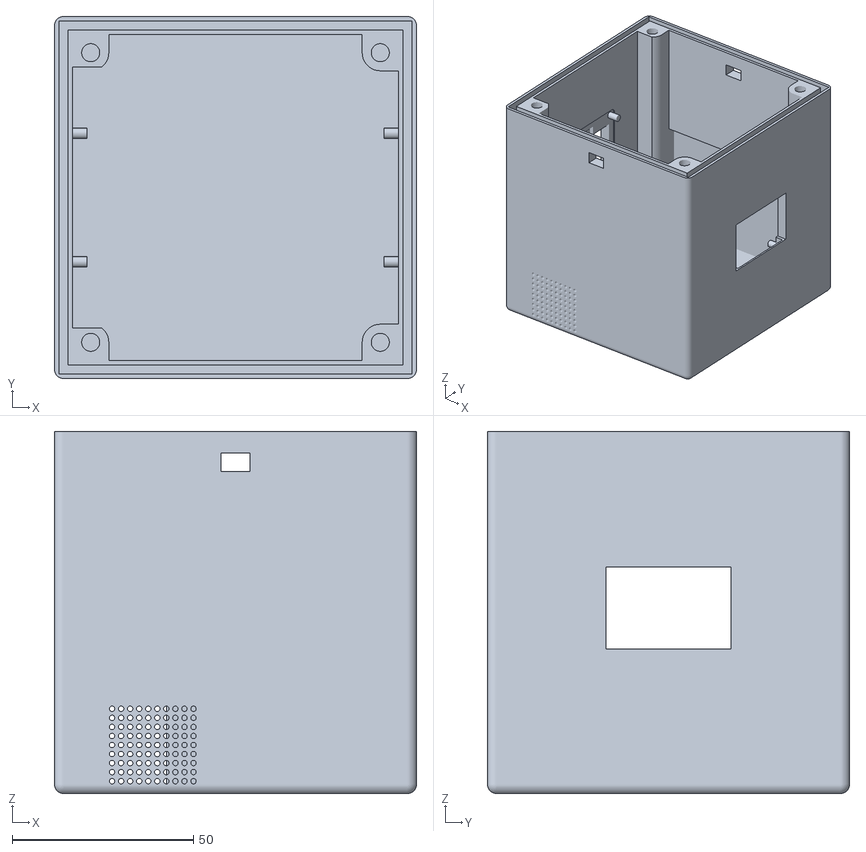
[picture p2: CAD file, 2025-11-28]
project_3D/stl/new_cube.stl
100.0 x 100.0 x 100.0

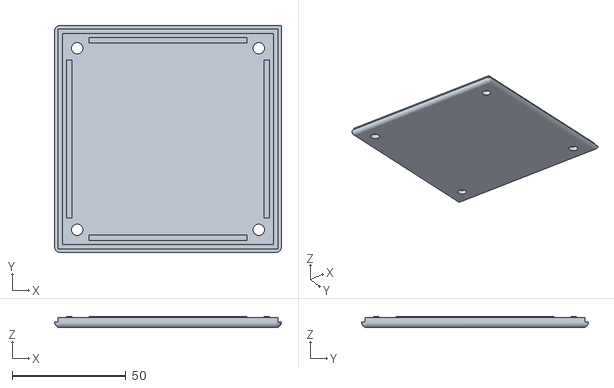
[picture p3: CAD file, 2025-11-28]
project_3D/stl/new_cap.stl
100.0 x 100.0 x 5.00

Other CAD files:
project_3D/f3z/HabCube.f3z

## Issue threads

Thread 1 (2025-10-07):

Wybór elementów potrzebnych do projektu

kurs0n, 2025-10-07:
Sensory, płytki, ekrany, buzzer, ogólny szkic projektu

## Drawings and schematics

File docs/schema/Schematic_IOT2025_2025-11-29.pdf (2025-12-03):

## Battery power supply 4.5V

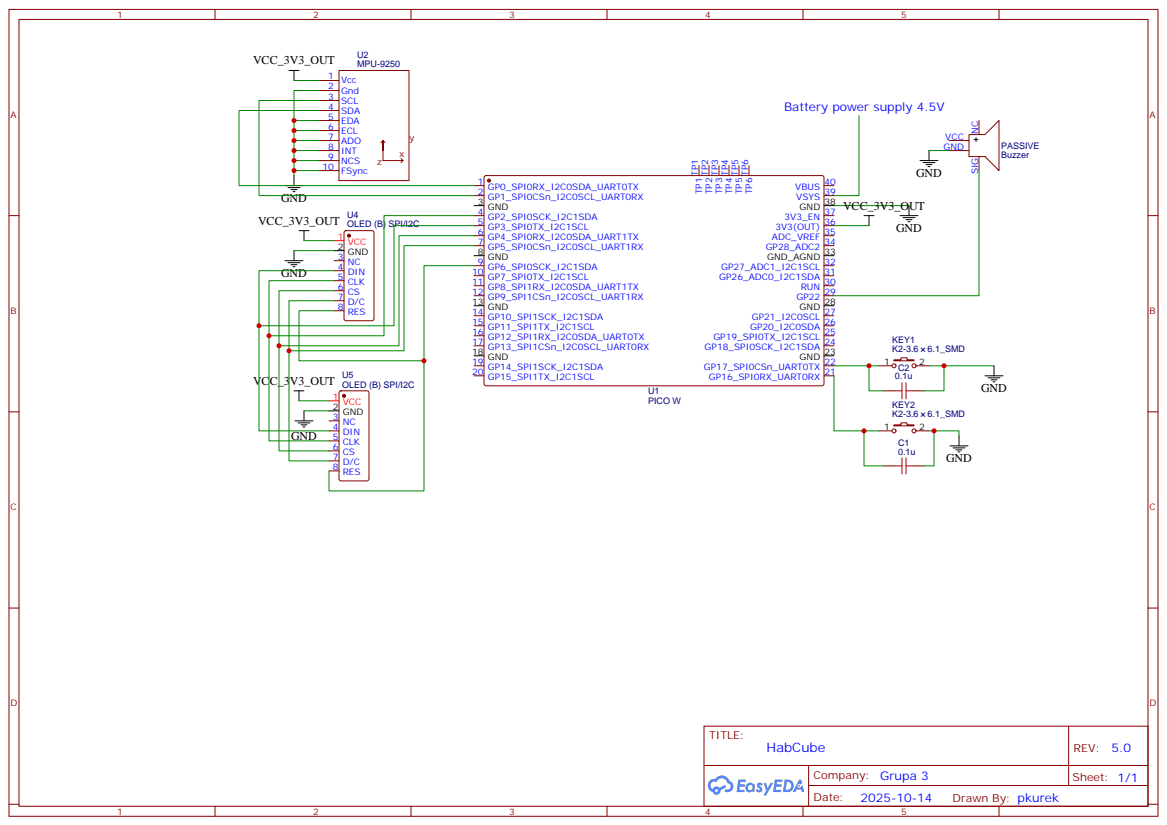
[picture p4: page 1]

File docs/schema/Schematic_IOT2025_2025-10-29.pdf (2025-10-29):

## Battery power supply 4.5V

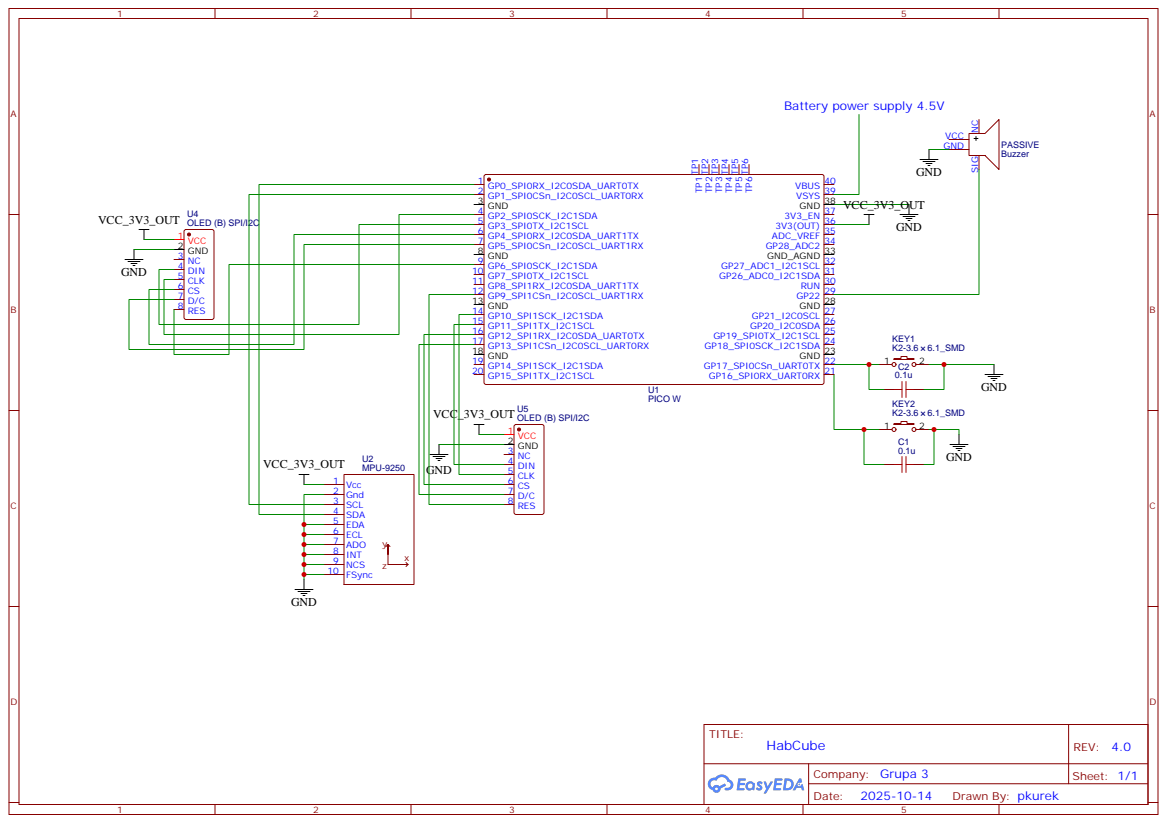
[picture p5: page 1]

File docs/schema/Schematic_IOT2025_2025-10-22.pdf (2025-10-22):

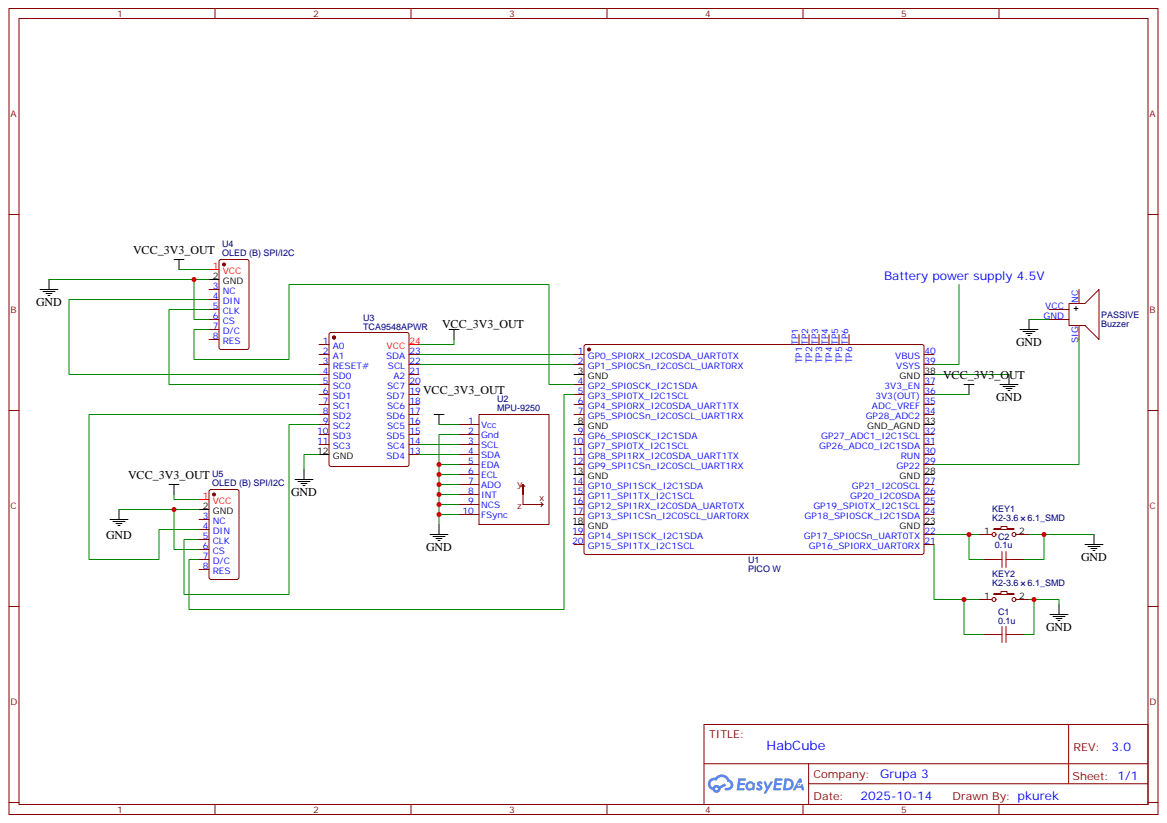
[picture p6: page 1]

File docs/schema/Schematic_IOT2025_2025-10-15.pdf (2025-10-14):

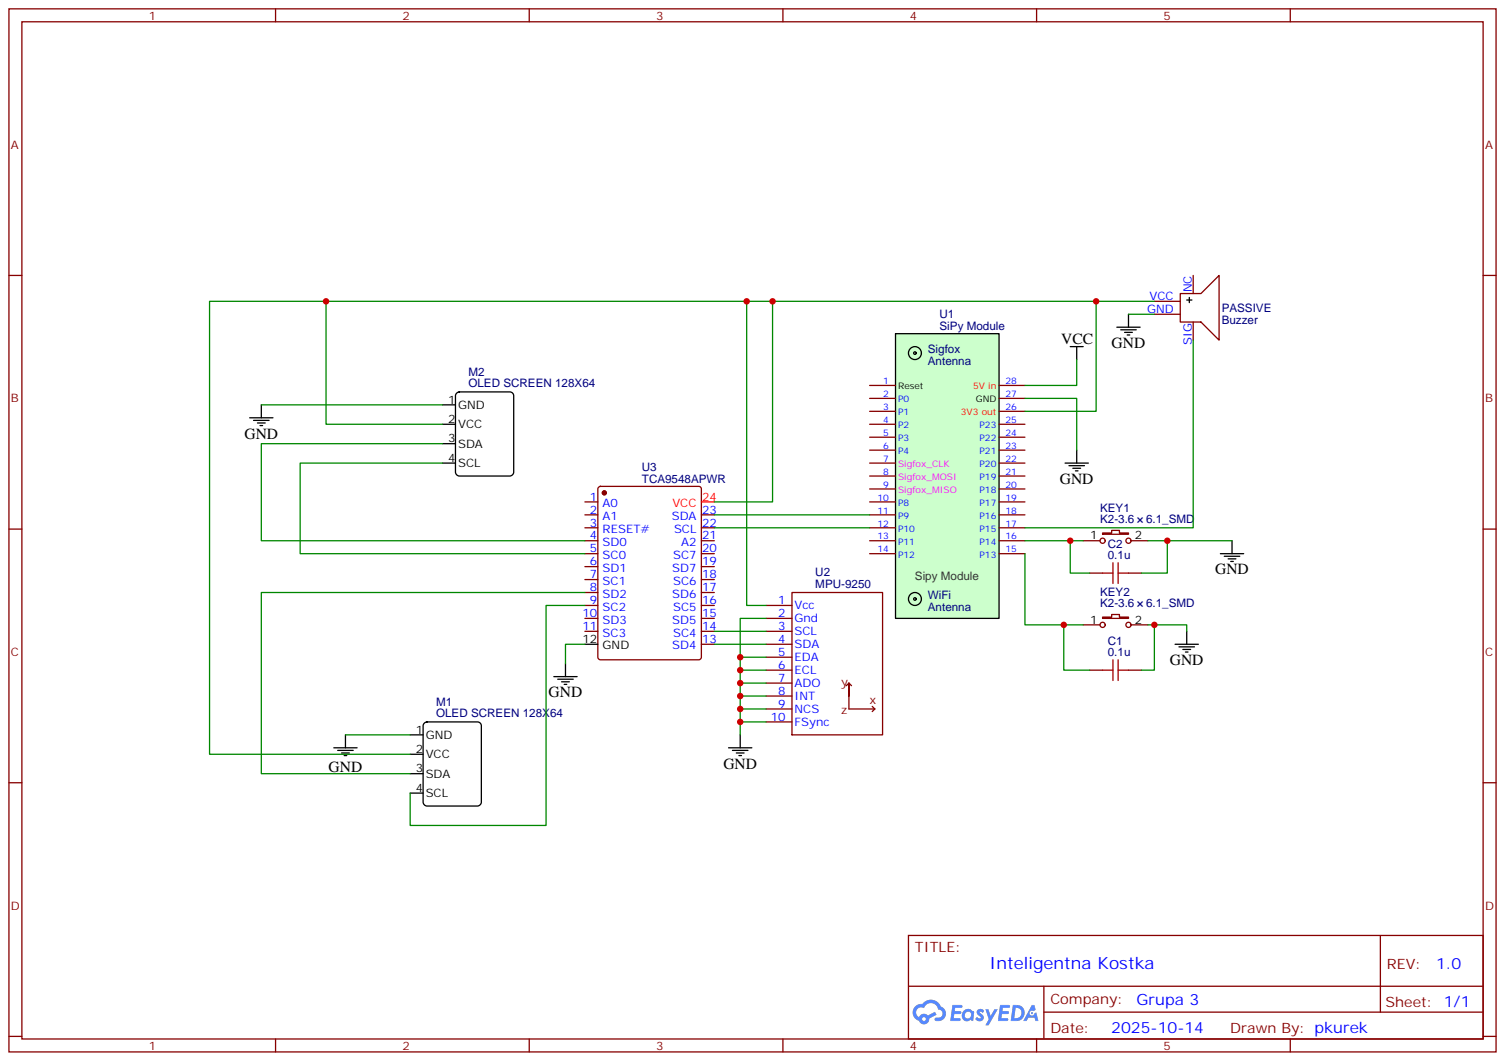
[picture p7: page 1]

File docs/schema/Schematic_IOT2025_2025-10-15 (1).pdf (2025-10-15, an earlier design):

## Battery power supply

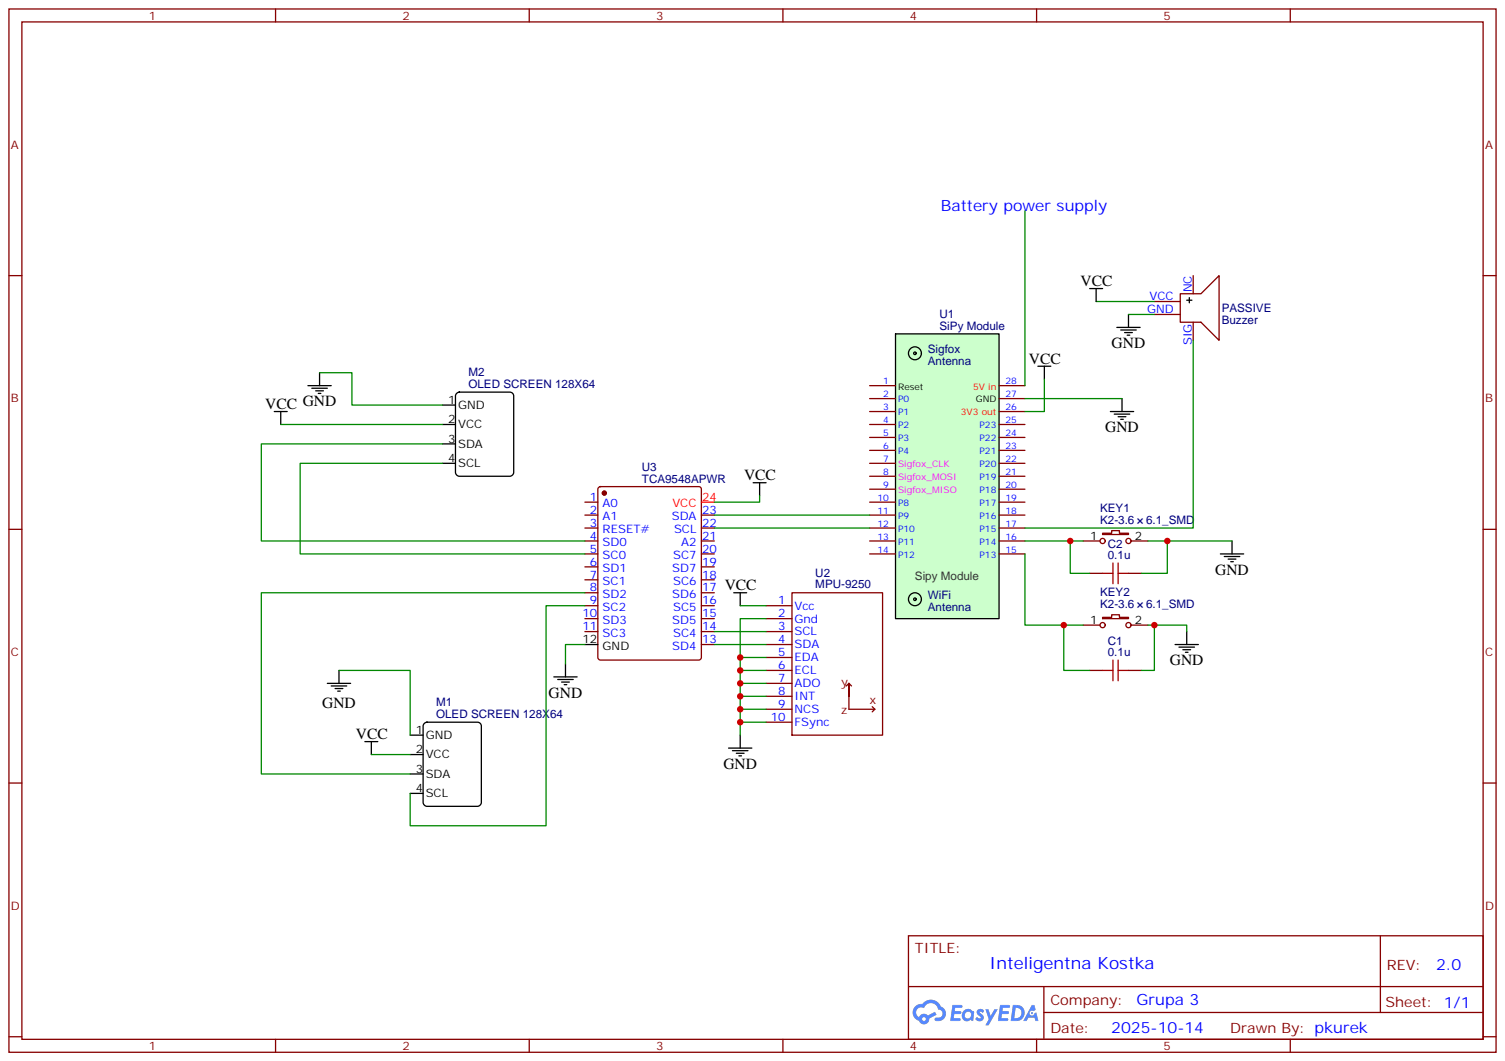
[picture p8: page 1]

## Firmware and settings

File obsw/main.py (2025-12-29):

import network
from time import sleep
from machine import Pin, PWM, I2C, SPI
import music
import utime
from mpu9250 import MPU9250
import requests
import json
import _thread
import icons
import captive 
import display

gyro_offset_z = 0
angle_z = 0
last_time = 0 
icons.configure_icons()

HOW_MANY_ANIMATION_PLAY = 5
active_habit_index = 0 
active_habits = []

buzzer = PWM(Pin(22))
buzzer.duty_u16(0)
i2c = I2C(0,sda=Pin(0),scl=Pin(1))

button1 = Pin(17,Pin.IN, Pin.PULL_UP)
button2 = Pin(16,Pin.IN, Pin.PULL_UP)
sensor = MPU9250(i2c)

def init():
    try: 
        f = open('wlan.info')
        data = f.read() 
        creds = data.split(" ")
        print(creds)
        if(not len(creds[0]) and not len(creds[1])):
            wlan = network.WLAN(network.STA_IF)
            wlan.active(False)
            wlan.active(True)
            ap = network.WLAN(network.AP_IF)
            ap.active(False)
            ap.active(True)
            ap.config(essid="HabCube", password="habcube2115")
            captive.start(ap,wlan)
        wlan = network.WLAN(network.STA_IF)
        wlan.active(False)
        wlan.active(True) 
        wlan.connect(creds[0], creds[1])
        connection_timeout = 10
        while( connection_timeout > 0):
            if wlan.isconnected():
                load_active_habits()
                break
            else:
                display.display_text_centered("Trying connecting to wifi...")
                print("not connected")
                connection_timeout -= 1
                sleep(1)
        if connection_timeout <=0:
            wlan = network.WLAN(network.STA_IF)
            wlan.active(False)
            wlan.active(True)
            ap = network.WLAN(network.AP_IF)
            ap.active(False)
            ap.active(True)
            ap.config(essid="HabCube", password="habcube2115") 
            captive.start(ap,wlan)
    except OSError:
        wlan = network.WLAN(network.STA_IF)
        wlan.active(False)
        wlan.active(True)
        ap = network.WLAN(network.AP_IF)
        ap.active(False)
        ap.active(True)
        ap.config(essid="HabCube", password="habcube2115")
        captive.start(ap,wlan)

    load_active_habits() 
 
    display.display_active_habit(active_habits,active_habit_index)
active_habits = [] 

def load_active_habits():
    global active_habits
    response = requests.get("https://backend-1089871134307.europe-west1.run.app/api/v1/habits/active")
    content = response.content
    habits = json.loads(content)
    active_habits = habits["habits"]
    
def calibrate_gyro(samples=200):
    print("Calibrate gyroscope...")
    sum_z = 0
    for _ in range(samples):
        sum_z += sensor.gyro[2]
        utime.sleep_ms(5)
    offset_z = sum_z / samples
    print(f"Calibrated gyroscope. Offset Z: {offset_z}")
    return offset_z  

def play_sui_animation():
    for _ in range(0,5):
        display.play_animation()


def complete_and_switch_habit():
    try:
        if len(active_habits) <= 0:
            return
        response = requests.post(f"https://backend-1089871134307.europe-west1.run.app/api/v1/habits/{str(active_habits[active_habit_index]["id"])}/complete",json={})
        print(response.content) 
        if (response.status_code == 200):
            active_habits.pop(active_habit_index)
            switch_next_habit()
    except requests.exceptions.HTTPError:
        print("error")
        return 


def switch_next_habit():
    global active_habit_index
    active_habit_index += 1
    if(active_habit_index >= len(active_habits)):
        active_habit_index = 0

def switch_previous_habit():
    global active_habit_index
    active_habit_index -= 1
    if(active_habit_index < 0):
        active_habit_index = len(active_habits) - 1 


def loop():
    global gyro_offset_z, angle_z, last_time
    
    gyro_offset_raw = calibrate_gyro() 
    
    angle_z = 0.0
    last_time = utime.ticks_ms()

    while True:
        if(button1.value() == 0 and button2.value() == 0):
            display.show_loading_screen()
            load_active_habits() 
            display.display_active_habit(active_habits,active_habit_index)
            angle_z = 0
        elif (button1.value() == 0):
            switch_previous_habit()
            display.display_active_habit(active_habits, active_habit_index)
            utime.sleep_ms(100)
            angle_z = 0
        elif (button2.value() == 0):
            switch_next_habit()
            display.display_active_habit(active_habits, active_habit_index)
            utime.sleep_ms(100)
            angle_z = 0

        
        current_time = utime.ticks_ms()
        dt = utime.ticks_diff(current_time, last_time) / 1000.0 
        last_time = current_time

        gyro_z_raw = sensor.gyro[2]
        
        gyro_z_rad = gyro_z_raw - gyro_offset_raw
        
        gyro_z_deg = gyro_z_rad * 57.296


        if abs(gyro_z_deg) < 0.5:
            gyro_z_deg = 0

        angle_z += gyro_z_deg * dt
        print(angle_z)
        if abs(angle_z) >= 160:        
            print("Rotation!")
            
            _thread.start_new_thread(music.play_mario_main_theme,(buzzer,))
            play_sui_animation()

            complete_and_switch_habit()

            gyro_offset_raw = calibrate_gyro() 
    
            angle_z = 0.0
            last_time = utime.ticks_ms()

            display.display_active_habit(active_habits, active_habit_index)

            angle_z = 0.0
            utime.sleep_ms(1000) 
            last_time = utime.ticks_ms() 

        utime.sleep_ms(10)
init()
loop()

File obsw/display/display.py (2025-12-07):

from machine import Pin, SPI
from sh1106 import SH1106_SPI
import icons
import framebuf
import utime 
spi_oled1 = SPI(0, baudrate=1000000, sck=Pin(2),mosi=Pin(3))
cs_oled1 = Pin(4, Pin.OUT, value=1)   
dc_oled1 = Pin(5, Pin.OUT)
rst_oled1 = Pin(6, Pin.OUT)

displays = SH1106_SPI(128, 64, spi_oled1, dc_oled1, rst_oled1, cs_oled1, rotate=0, delay=0)   

def display_text_centered(text):
    global displays

    displays.fill(0)

    SCREEN_WIDTH = 128
    SCREEN_HEIGHT = 64
    CHAR_WIDTH = 8
    CHAR_HEIGHT = 8
    MAX_CHARS_PER_LINE = SCREEN_WIDTH // CHAR_WIDTH  

    lines = []
    for i in range(0, len(text), MAX_CHARS_PER_LINE):
        lines.append(text[i:i + MAX_CHARS_PER_LINE])
    
    total_text_height = len(lines) * CHAR_HEIGHT
    y_start = (SCREEN_HEIGHT - total_text_height) // 2
    
    for i, line in enumerate(lines):
        line_width = len(line) * CHAR_WIDTH
        x_pos = (SCREEN_WIDTH - line_width) // 2

        y_pos = y_start + (i * CHAR_HEIGHT)
        
        displays.text(line, x_pos, y_pos, 1) 

    displays.show()

def display_active_habit(active_habits,active_habit_index):
    if len(active_habits) <= 0:
        display_text_centered("No active habits try adding one in mobile app")
        return
    habit_name = active_habits[active_habit_index]["name"]
    displays.fill(0)
    x_icon = (128 - 80) // 2

    if(active_habits[active_habit_index]["type"]== "water"):
        displays.blit(icons.fb_glass,x_icon,0)
   
    elif (active_habits[active_habit_index]["type"] =="sport"):
        displays.blit(icons.fb_sport,x_icon,0)
    elif (active_habits[active_habit_index]["type"]=="language"):
        displays.blit(icons.fb_lang,x_icon,0)
    elif(active_habits[active_habit_index]["type"] == "read"): 
        displays.blit(icons.fb_glasses,x_icon,0)
    elif (active_habits[active_habit_index]["type"] == "code"):
        displays.blit(icons.fb_code,x_icon,0)
   
    max_chars = 16 
    
    if len(habit_name) > max_chars:
        habit_name = habit_name[:max_chars - 3] + "..." 

    text_length = len(habit_name) * 8
    x_text = (128 - text_length) // 2
    y_text = 52
    if(x_text < 0):
        x_text = 0
    displays.text(habit_name,x_text,y_text,1)
    displays.show()    

def show_loading_screen():
    displays.fill(0)
    text_length = len("Loading Habits...") * 8
    x_text = (128 - text_length) // 2
    y_text = 22
    if(x_text < 0):
        x_text = 0
    displays.text("Loading Habits...",x_text,y_text,1)
    displays.show()    

def play_animation(frame_delay_ms=5):
    global displays
    frame_number = 1
    while True:
            filename = f"resized_{frame_number}.bmp"
            try:
                with open(filename, "rb") as f:
                        f.seek(10)
                        data_offset = int.from_bytes(f.read(4), "little")
                        f.seek(data_offset)
                        buffer = f.read()
                        fb = framebuf.FrameBuffer(bytearray(buffer), 128, 64, framebuf.MONO_HLSB)
                        
                        displays.fill(0)
                        displays.blit(fb, 0, 0)
                        displays.show()
                        
                        utime.sleep_ms(frame_delay_ms)
                        frame_number += 1

            except OSError:
                if frame_number == 1:
                    print(f"End Animation")
                else:
                    print("End animation")
                break 

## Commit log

2025-10-22 refactor: changed board to raspberry pico w. changed schema
2025-10-23 Enhance README with data flow diagrams
    Added detailed flowcharts for habit creation, completion, and progress monitoring in the README.
2025-10-28 refactor: removed multiplexer and use second spi to adjust second screen
2025-10-29 feat: obsw button code and schema
2025-11-03 Update 3D project
    [HubCube.f3d, cap.stl]
2025-11-17 Fix: Single worker with threads + preload to avoid OOM, remove debug prints, fix double return
2025-11-26 feat: initial captive portal but with bugs
    [main.py]
2025-11-27 Update 3D project v2
    [HabCube.f3z, HubCube.f3z, cap.stl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]
2025-11-29 refactor: display on one spi interface
2025-12-07 Update number of OLED screens in assembly instructions
2025-12-07 Add data flow diagram to documentation
    Added a detailed data flow diagram for the system, illustrating user interactions, device communication, backend processes, and error handling.
2025-12-07 Revise data flow diagrams for habit management
    Updated diagrams and descriptions for user interaction with habits, including new functionality for fetching habits and creating new habits.
2025-12-29 feat: prototype video
